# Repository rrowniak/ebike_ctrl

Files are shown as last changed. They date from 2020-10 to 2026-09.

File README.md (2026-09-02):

# ebike_ctrl
A small but powerful on-board computer displaying main parameters of almost any electric bike.
It concists of three parts:
* Motherboard - sits close to the BLDC driver and battery. Main responsibility is to gather all needed data like battery voltage, temperatures, current, hall sensor output and so on. The motherboard communicates with UI module via CAN bus.
* Current sensor. This is a hardware module (no firmware needed) connected to the motherboard.
* UI - displays all valuable info to a user. It reads what the motherboard is sending via CAN bus, then interprets the data, does additional calculations and displays on EA DOGXL240W-7 (240x128 pixel COG LCD).

## Features

* Displays current up to +/- 100A, voltage up to 100V and battery percentage

* Current speed, distance traveled (three profiles)

* Consumption in Wh, Wh/km +gain from regenerative charging

* Temperatures: ambient, motor, battery, driver

* Allows for changing views

* and more

## Requirements and dependencies

* GNU Arm Embedded Toolchain

* [l_rr library](https://github.com/rrowniak/l_rr)

## License

Copyright (c) 2020 Rafal Rowniak rrowniak.com

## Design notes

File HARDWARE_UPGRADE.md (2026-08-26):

# Hardware Upgrade Plan

The ebike controller consists of two independent STM32 units — **Motherboard** and **UI**.
This document tracks the planned hardware upgrade, split into two phases.

## Phase 1 — UI Unit

Replaces the current STM32F103C8 + HD44780 16×2 LCD with modern components.

### Selected parts

| Component | Part | Role |
|---|---|---|
| MCU | **NUCLEO-G431KB** (STM32G431CB in UFQFPN32 package, 128 KB flash / 32 KB RAM) | Main controller, FDCAN, better ADC |
| Display | **EA DOGXL240W-7** (240×128 COG LCD, SPI) | Primary display — sunlight-readable |
| Temperature sensor | **LM35** (analog output, −55…+150 °C) | Ambient/display temperature monitoring |
| EEPROM | **24L256** (256 Kbit I²C) | Vehicle configuration storage |
| CAN transceiver | **MCP2562** (high-speed CAN) | CAN bus interface to Motherboard |

### Rationale

- **STM32G431CB** — active product (≥2036), FDCAN (CAN 2.0 compatible), 12-bit ADC with
  hardware oversampling, 32 KB RAM handles the new display framebuffer, same CubeMX/HAL
  workflow. See `MCU.md` for full analysis.
- **EA DOGXL240W-7** — 240×128 COG LCD with SPI, sunlight-readable, bare-metal driver
  friendly. Replaces the Sharp Memory LCD option from earlier discussions.
- **LM35** — simple analog temperature sensor, direct ADC read, no digital protocol needed.
- **24L256** — same I²C EEPROM family already used in the current UI firmware
  (`lrr_eeprom_24LC256`), straightforward port.
- **MCP2562** — CAN 2.0 high-speed transceiver; pairs with the G431's FDCAN peripheral.

### Key files

- `UI/firmware/` — the old UI firmware project (CubeMX-generated, `firmware.ioc`)
- `UI/firmware2/` — the new/current UI firmware project (CubeMX-generated, `firmware2.ioc`)
- `include/bike_can_protocol.h` — shared CAN wire format (both sides)

### Migration notes

- FDCAN HAL API differs from bxCAN — `Src/can.c` and its test fake must be reworked.
- Display driver is new; existing `ui.c` abstraction layer keeps app logic untouched.
- `l_rr` library drivers need porting to G4 HAL; matching `stm32_drv_fake` fakes too.
- Deploy path (UART bootloader via `deploy.sh`) is preserved on the G431.

## Phase 2 — Motherboard + BMS

Upgrade the Motherboard unit (and potentially the BMS) to the same MCU family.
TBD — details to be added once Phase 1 is complete.

## Timeline

| Phase | Scope | Status |
|---|---|---|
| Phase 1 | UI unit only | In progress |
| Phase 2 | Motherboard + BMS | Planned |

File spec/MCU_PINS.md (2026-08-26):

# STM32G431KB Pin Reference & NUCLEO-G431KB Board Constraints

> Source: DS12589 Rev 6 (datasheet), RM0440 (reference manual), UM2397 Rev 2 (NUCLEO-G431KB user manual)
> Package: UFQFPN32 / LQFP32 — 32 pins total
>
> **⚠️ This document covers the full G4 family. For the UFQFPN32 package (STM32G431KB),
> only PA0–PA15, PB0, PB3–PB8, and PF0–PF1 are bonded out. Pins marked ✕ in the AF
> tables do NOT exist on the 32-pin package. See Section 7, Note 1 for details.**

---

## 1. STM32G431KB LQFP32 Pin Map

| Pin | Name | Type | Notes |
|-----|---|---|---|
| 1 | VDD | Power | 1.71–3.6V |
| 2 | PF0 / OSC_IN | I/O | HSE oscillator input |
| 3 | PF1 / OSC_OUT | I/O | HSE oscillator output |
| 4 | PG10 / NRST | I/O | Reset (active low) — **not available as GPIO** |
| 5 | PA0 | I/O | ADC1_IN1 |
| 6 | PA1 | I/O | ADC1_IN2 |
| 7 | PA2 | I/O | ADC1_IN3 |
| 8 | PA3 | I/O | ADC1_IN4 |
| 9 | PA4 | I/O | ADC1_IN5 |
| 10 | PA5 | I/O | ADC1_IN6 |
| 11 | PA6 | I/O | ADC1_IN7 |
| 12 | PA7 | I/O | ADC1_IN8 |
| 13 | PA8 | I/O | — |
| 14 | PA9 | I/O | — |
| 15 | PA10 | I/O | — |
| 16 | PA11 | I/O | ADC2_IN11 |
| 17 | PA12 | I/O | ADC2_IN12 |
| 18 | VSS | Power | Ground |
| 19 | PA13 | I/O | **SWDIO** (debug) |
| 20 | PA14 | I/O | **SWCLK** (debug) |
| 21 | VDDA | Power | Analog supply |
| 22 | VSS | Power | Ground |
| 23 | PB0 | I/O | ADC1_IN1 / ADC2_IN1 |
| 24 | VDD | Power | — |
| 25 | PB8 / BOOT0 | I/O | BOOT0 selection |
| 26 | PB7 | I/O | — |
| 27 | PB6 | I/O | — |
| 28 | PB5 | I/O | — |
| 29 | PB4 | I/O | — |
| 30 | PB3 | I/O | — |
| 31 | PA15 | I/O | — |
| 32 | VSS | Power | Ground |

---

## 2. Alternate Function Mapping (DS12589 Table 13)

### AF Number Assignment Summary

| AF | Peripheral Group |
|----|---|
| AF0 | SYS_AF: MCO, SWD (SWDIO/SWCLK), JTAG (JTDI/JTDO/NJTRST), TRACE, RTC_REFIN |
| AF1 | LPTIM1, TIM1/TIM2/TIM15/TIM16/TIM17 |
| AF2 | TIM1/TIM2/TIM3/TIM4/TIM8/TIM15, GPCOMP |
| AF3 | SAI1, USB, TIM8/TIM15, GPCOMP, I2C3 |
| AF4 | I2C1/I2C2/I2C3, TIM1/TIM8/TIM16/TIM17 |
| AF5 | SPI1/SPI2/SPI3, I2S2/I2S3, UART4 |
| AF6 | SPI2/SPI3, I2S2/I2S3, TIM1/TIM8 |
| AF7 | USART1/USART2/USART3 |
| AF8 | I2C3/I2C4, UART4, LPUART1, GPCOMP |
| AF9 | TIM1/TIM8/TIM15, FDCAN1 |
| AF10 | TIM2/TIM3/TIM4/TIM8/TIM17, LPTIM1, FDCAN1 |
| AF11 | LPUART1, SAI1, TIM1 |
| AF12 | SAI1, OPAMP2 |
| AF13 | UART4, SAI1, TIM2/TIM15, UCPD1 |
| AF14 | Reserved |
| AF15 | EVENTOUT |

---

### PORT A — Full AF Table

| Pin | AF0 | AF1 | AF2 | AF3 | AF4 | AF5 | AF6 | AF7 | AF8 | AF9 | AF10 | AF11 | AF12 | AF13 | AF15 |
|-----|-----|-----|-----|-----|-----|-----|-----|-----|-----|-----|---|---|---|---|---|
| PA0 | — | TIM2_CH1 | — | COMP1_OUT | — | — | — | USART2_CTS | — | — | COMP1_OUT | LPUART1_CTS | OPAMP1_OUT | — | EVENTOUT |
| PA1 | — | TIM2_CH2 | TIM15_CH1 | COMP1_OUT | — | — | — | USART2_RTS_DE | — | — | COMP1_OUT | LPUART1_RTS_DE | OPAMP2_OUT | SAI1_MCLK_A | EVENTOUT |
| PA2 | — | TIM2_CH3 | TIM15_CH2 | — | — | — | — | USART2_TX | LPUART1_TX | — | COMP2_OUT | — | — | SAI1_SCK_A | EVENTOUT |
| PA3 | — | TIM2_CH4 | — | COMP1_OUT | — | — | — | USART2_RX | LPUART1_RX | — | COMP2_OUT | — | — | SAI1_FS_A | EVENTOUT |
| PA4 | — | — | — | COMP1_OUT | — | SPI1_NSS | SPI3_NSS | USART2_CK | — | — | — | — | — | — | EVENTOUT |
| PA5 | — | TIM2_CH1 | TIM2_ETR | COMP1_OUT | — | SPI1_SCK | — | — | — | — | — | — | — | — | EVENTOUT |
| PA6 | — | TIM3_CH1 | TIM15_CH1 | — | TIM16_BKIN | SPI1_MISO | — | — | — | COMP2_OUT | — | — | — | SAI1_SCK_B | EVENTOUT |
| PA7 | — | TIM3_CH2 | TIM17_CH1 | COMP1_OUT | TIM17_CH2 | SPI1_MOSI | — | — | — | — | — | — | — | SAI1_FS_B | EVENTOUT |
| PA8 | MCO | TIM1_CH1 | — | — | — | — | SPI1_MOSI | USART1_CK | — | TIM8_BKIN2 | FDCAN1_TX | — | — | — | EVENTOUT |
| PA9 | — | TIM1_CH2 | — | — | — | — | SPI1_SCK | USART1_TX | I2C3_SCL | — | FDCAN1_RX | LPUART1_TX | — | — | EVENTOUT |
| PA10 | — | TIM1_CH3 | — | — | — | — | SPI1_MISO | USART1_RX | I2C3_SDA | — | — | LPUART1_RX | — | — | EVENTOUT |
| PA11 | — | TIM1_CH4 | — | COMP1_OUT | I2C1_SDA | — | — | USART1_CTS | — | FDCAN1_RX¹ | USB_DM | — | — | — | EVENTOUT |
| PA12 | — | — | — | COMP1_OUT | I2C1_SCL | — | — | USART1_RTS_DE | — | FDCAN1_TX¹ | USB_DP | — | — | — | EVENTOUT |
| PA13 | SWDIO | — | — | — | I2C1_SCL | — | — | — | — | — | — | — | — | — | EVENTOUT |
| PA14 | SWCLK | — | — | — | I2C1_SDA | — | — | — | — | TIM1_BKIN | USART2_TX | SAI1_FS_B | — | — | EVENTOUT |
| PA15 | JTDI | TIM2_CH1 | TIM8_CH1 | — | I2C1_SCL | SPI1_NSS | SPI3_NSS | USART2_RX | UART4_RTS_DE | TIM1_BKIN | TIM2_ETR | — | — | — | EVENTOUT |

> ¹ AF9 on PA11/PA12: The datasheet (DS12589 Table 13) lists TIM1_BKIN2 (PA11) and
> TIM1_ETR (PA12) on AF9. However, **CubeMX and ST community reports confirm FDCAN1_RX
> on PA11 and FDCAN1_TX on PA12 as AF9** for the G431KB. The entries above reflect the
> CubeMX-verified mapping. If using a different G4 variant, verify against your specific
> datasheet revision.

### PORT B — Full AF Table

> **Pins marked ✕ are NOT bonded out on UFQFPN32/LQFP32 (STM32G431KB).** They exist on
> LQFP48+ packages (G431CB, G431RB, etc.) but cannot be used on the 32-pin variant.

| Pin | AF0 | AF1 | AF2 | AF3 | AF4 | AF5 | AF6 | AF7 | AF8 | AF9 | AF10 | AF11 | AF12 | AF13 | AF15 |
|-----|-----|-----|-----|-----|-----|-----|-----|-----|-----|-----|---|---|---|---|---|
| PB0 | — | — | TIM3_CH3 | TIM1_ETR | TIM16_CH1 | — | SPI1_MOSI | — | — | TIM3_ETR | — | — | — | OPAMP1_OUT | EVENTOUT |
| PB1 ✕ | — | — | TIM3_CH4 | — | TIM16_CH1N | — | — | USART3_RTS_DE | — | — | — | LPUART1_RTS_DE | OPAMP1_OUT | OPAMP3_OUT | EVENTOUT |
| PB2 ✕ | — | — | — | — | — | — | — | — | — | — | — | — | — | — | EVENTOUT |
| PB3 | JTDO | — | — | — | — | SPI1_SCK | SPI3_SCK | — | — | — | — | — | — | — | EVENTOUT |
| PB4 | NJTRST | — | TIM3_CH1 | — | — | SPI1_MISO | SPI3_MISO | — | — | — | — | — | — | — | EVENTOUT |
| PB5 | — | LPTIM1_IN1 | TIM3_CH2 | — | I2C1_SMBA | SPI1_MOSI | — | — | — | — | — | — | — | — | EVENTOUT |
| PB6 | — | LPTIM1_ETR | TIM4_CH1 | SAI1_FS_B | I2C1_SCL | — | — | USART1_TX | — | — | — | — | — | — | EVENTOUT |
| PB7 | — | LPTIM1_IN2 | TIM4_CH2 | — | I2C1_SDA | — | — | USART1_RX | — | — | — | — | — | — | EVENTOUT |
| PB8 | — | — | TIM4_CH3 | SAI1_SCK_A | — | SPI1_SCK | — | — | I2C1_SCL | TIM16_CH1 | — | — | — | SAI1_FS_B | EVENTOUT |
| PB9 ✕ | — | TIM17_CH1 | TIM4_CH4 | SAI1_D2 | I2C1_SDA | IR_OUT | — | USART3_TX | COMP2_OUT | FDCAN1_TX | TIM8_CH3 | TIM1_CH3N | SAI1_FS_A | — | EVENTOUT |
| PB10 ✕ | — | — | TIM2_CH3 | SAI1_SCK_B | I2C2_SCL | SPI2_SCK | — | USART3_TX | — | FDCAN1_TX | — | — | — | — | EVENTOUT |
| PB11 ✕ | — | — | TIM2_CH4 | SAI1_D2 | I2C2_SDA | — | — | USART3_RX | — | FDCAN1_RX | — | — | — | — | EVENTOUT |
| PB12 ✕ | — | LPTIM1_OUT | — | COMP2_OUT | I2C2_SMBA | SPI2_NSS | — | USART3_CK | — | FDCAN1_RX | — | — | — | — | EVENTOUT |
| PB13 ✕ | — | — | — | COMP4_OUT | I2C2_SCL | SPI2_SCK | TIM1_CH1N | USART3_CTS | LPUART1_CTS | — | — | — | — | — | EVENTOUT |
| PB14 ✕ | — | TIM15_CH1 | — | — | I2C2_SDA | SPI2_MISO | TIM1_CH2N | USART3_RTS_DE | COMP4_OUT | — | — | — | — | — | EVENTOUT |
| PB15 ✕ | RTC_REFIN | TIM15_CH2 | TIM15_CH1N | COMP3_OUT | TIM1_CH3N | SPI2_MOSI | — | — | — | — | — | — | — | — | EVENTOUT |

### PORT C — Full AF Table

> **All PORT C pins are ✕ NOT available on UFQFPN32/LQFP32 (STM32G431KB).**
> Included for reference when using LQFP48+ packages.

| Pin | AF0 | AF1 | AF2 | AF3 | AF4 | AF5 | AF6 | AF7 | AF8 | AF15 |
|-----|-----|-----|-----|-----|-----|-----|-----|-----|-----|---|
| PC0 ✕ | — | — | — | — | — | — | — | — | LPTIM1_IN1 | EVENTOUT |
| PC1 ✕ | — | — | — | — | — | — | — | — | LPTIM1_OUT | EVENTOUT |
| PC2 ✕ | — | — | — | — | — | — | — | — | LPTIM1_IN3 | EVENTOUT |
| PC3 ✕ | — | — | — | — | — | — | — | — | LPTIM1_ETR | EVENTOUT |
| PC4 ✕ | — | — | — | COMP1_OUT | — | — | — | — | LPTIM1_IN2 | EVENTOUT |
| PC5 ✕ | — | — | — | COMP1_OUT | — | — | — | — | LPTIM1_IN1 | EVENTOUT |
| PC6 ✕ | — | TIM3_CH1 | TIM8_CH1 | — | — | — | I2S2_MCK | — | — | EVENTOUT |
| PC7 ✕ | — | TIM3_CH2 | TIM8_CH2 | — | — | — | — | — | — | EVENTOUT |
| PC8 ✕ | — | TIM3_CH3 | TIM8_CH3 | — | — | — | — | — | — | EVENTOUT |
| PC9 ✕ | — | TIM3_CH4 | TIM8_CH4 | — | — | — | — | — | — | EVENTOUT |
| PC10 ✕ | — | — | TIM8_CH1N | — | — | UART4_TX | SPI3_SCK | USART3_TX | — | EVENTOUT |
| PC11 ✕ | — | — | TIM8_CH2N | — | — | UART4_RX | SPI3_MISO | USART3_RX | I2C3_SDA | EVENTOUT |
| PC12 ✕ | — | — | TIM8_CH3N | — | TIM8_CH4 | — | SPI3_MOSI | USART3_CK | UCPD1_FRSTX | EVENTOUT |
| PC13 ✕ | — | — | TIM1_BKIN | — | TIM1_CH1N | — | TIM8_CH4N | — | — | EVENTOUT |
| PC14 ✕ | — | — | — | — | — | — | — | — | — | EVENTOUT |
| PC15 ✕ | — | — | — | — | — | — | — | — | — | EVENTOUT |

### PORT F — Full AF Table

> **PF2, PF9, PF10 are ✕ NOT available on UFQFPN32/LQFP32.**
> PF0/PF1 are available but primarily for HSE oscillator (requires SB8/SB11 on NUCLEO).

| Pin | AF0 | AF1 | AF2 | AF3 | AF4 | AF5 | AF6 | AF7 | AF8 | AF15 |
|-----|-----|-----|-----|-----|-----|-----|-----|-----|-----|---|
| PF0 | — | — | — | — | I2C2_SDA | SPI2_NSS | TIM1_CH3N | — | — | EVENTOUT |
| PF1 | — | — | — | — | — | SPI2_SCK | — | — | — | EVENTOUT |
| PF2 ✕ | — | — | — | — | I2C2_SMBA | — | — | — | — | EVENTOUT |
| PF9 ✕ | — | — | TIM15_CH1 | — | — | SPI2_SCK | — | — | — | EVENTOUT |
| PF10 ✕ | — | — | TIM15_CH2 | — | — | SPI2_SCK | — | — | — | EVENTOUT |

### PORT G

| Pin | AF0 | AF15 | Notes |
|-----|-----|---|---|
| PG10 | MCO | EVENTOUT | **NRST pin — not available as GPIO** on any package |

---

## 3. Peripheral-to-Pin Conflict Matrix

When a peripheral is mapped to a pin, **all other AFs on that pin become unavailable**. Below are the key conflicts for each peripheral.

> **Pins marked ✕ are NOT available on UFQFPN32.** Conflict info is included for LQFP48+ reference.

### I2C1

| Signal | Available Pins (UFQFPN32) | AF | Conflicts |
|---|---|-----|---|
| I2C1_SCL | PA13, PA15, PB6, PB8 | AF4 | PA13=SWDIO, PA15=SPI1_NSS/USART2_RX/JTDI, PB6=USART1_TX, PB8=SPI1_SCK |
| I2C1_SDA | PA11, PA14, PB7, PB5 | AF4 | PA11=USB_DM/FDCAN1_RX, PA14=SWCLK/USART2_TX, PB7=USART1_RX, PB5=SPI1_MOSI |
| I2C1_SMBA | PB5 | AF4 | PB5=SPI1_MOSI/TIM3_CH2 |

**I2C1 conflicts (UFQFPN32):**
- PA13+PA14: SWD pins — **cannot use for I2C1** without losing debug
- PA15+PB7: Common NUCLEO I2C pair (SB2/SB3) — conflicts with USART2_RX and USART1_RX
- PB6+PB7: TIM4_CH1/TIM4_CH2 and USART1_TX/USART1_RX — using I2C1 here blocks USART1

### I2C2

| Signal | Available Pins (UFQFPN32) | AF | Conflicts |
|---|---|-----|---|
| I2C2_SCL | PF0 (oscillator only) | AF4 | PF0=OSC_IN — only available without external crystal |
| I2C2_SDA | PF0 (oscillator only) | AF4 | PF0=OSC_IN — only available without external crystal |
| I2C2_SMBA | PF2 ✕ | AF4 | Not available on UFQFPN32 |

**I2C2 conflicts:**
- **No practical I2C2 option on UFQFPN32** — PB10/PB11/PB12/PB13 are not bonded out
- PF0 can serve as I2C2_SDA but conflicts with HSE oscillator
- PF0: Only available when not using external crystal

### I2C3

| Signal | Available Pins (UFQFPN32) | AF | Conflicts |
|---|---|-----|---|
| I2C3_SCL | PA9, PA13, PA15, PB8 | AF4 | PA9=USART1_TX/SPI1_SCK, PA13=SWDIO, PA15=JTDI/USART2_RX, PB8=SPI1_SCK |
| I2C3_SDA | PA10, PA14 | AF4 | PA10=USART1_RX, PA14=SWCLK/USART2_TX |

### USART1

| Signal | Available Pins (UFQFPN32) | AF | Conflicts |
|---|---|-----|---|
| USART1_TX | PA9, PB6 | AF7 | PA9=SPI1_SCK/I2C3_SCL, PB6=TIM4_CH1/I2C1_SCL |
| USART1_RX | PA10, PB7 | AF7 | PA10=SPI1_MISO/I2C3_SDA, PB7=TIM4_CH2/I2C1_SDA |
| USART1_CTS | PA11 | AF7 | PA11=FDCAN1_RX/USB_DM |
| USART1_RTS_DE | PA12 | AF7 | PA12=FDCAN1_TX/USB_DP |
| USART1_CK | PA8 | AF7 | PA8=MCO/TIM1_CH1 |

### USART2

| Signal | Available Pins (UFQFPN32) | AF | Conflicts |
|---|---|-----|---|
| USART2_TX | PA2, PA14 | AF7 | PA2=LPUART1_TX/COMP2_OUT (default VCP on NUCLEO), PA14=SWCLK |
| USART2_RX | PA3, PA15 | AF7 | PA3=LPUART1_RX/COMP2_OUT (default VCP on NUCLEO), PA15=JTDI/SPI1_NSS |
| USART2_CTS | PA0 | AF7 | PA0=TIM2_CH1/COMP1_OUT |
| USART2_RTS_DE | PA1 | AF7 | PA1=TIM2_CH2/LPUART1_RTS_DE |
| USART2_CK | PA4 | AF7 | PA4=SPI1_NSS/SPI3_NSS |

### USART3

| Signal | Available Pins (UFQFPN32) | AF | Conflicts |
|---|---|-----|---|
| USART3_TX | **None** ✕ | AF7 | PB9/PB10/PC10 not available on UFQFPN32 |
| USART3_RX | **None** ✕ | AF7 | PB11/PC11 not available on UFQFPN32 |
| USART3_CK | **None** ✕ | AF7 | PB12/PC12 not available on UFQFPN32 |
| USART3_CTS | **None** ✕ | AF7 | PB13 not available on UFQFPN32 |
| USART3_RTS_DE | **None** ✕ | AF7 | PB1/PB14 not available on UFQFPN32 |

> **USART3 is not usable on UFQFPN32** — all USART3 pins require PB9–PB15 or PC pins.

### LPUART1

| Signal | Available Pins (UFQFPN32) | AF | Conflicts |
|---|---|-----|---|
| LPUART1_TX | PA2, PA9 | AF8 | PA2=USART2_TX (default VCP), PA9=USART1_TX/SPI1_SCK |
| LPUART1_RX | PA3, PA10 | AF8 | PA3=USART2_RX (default VCP), PA10=USART1_RX/SPI1_MISO |
| LPUART1_CTS | PA0 | AF8 | PA0=TIM2_CH1 |
| LPUART1_RTS_DE | PA1 | AF8 | PA1=TIM2_CH2 |

### UART4

| Signal | Available Pins (UFQFPN32) | AF | Conflicts |
|---|---|-----|---|
| UART4_TX | **None** ✕ | AF5 | PC10 not available on UFQFPN32 |
| UART4_RX | **None** ✕ | AF5 | PC11 not available on UFQFPN32 |
| UART4_RTS_DE | PA15 | AF8 | PA15=JTDI/SPI1_NSS/USART2_RX |

> **UART4 TX/RX not usable on UFQFPN32** — requires PC10/PC11.

### SPI1

| Signal | Available Pins (UFQFPN32) | AF | Conflicts |
|---|---|-----|---|
| SPI1_SCK | PA5, PA9, PB3 | AF5 | PA5=TIM2_CH1 (SB2 constraint), PA9=USART1_TX/I2C3_SCL, PB3=JTDO/SPI3_SCK |
| SPI1_MISO | PA6, PA10, PB4 | AF5 | PA6=TIM3_CH1 (SB3 constraint), PA10=USART1_RX/I2C3_SDA, PB4=NJTRST/SPI3_MISO |
| SPI1_MOSI | PA7, PA8, PB5 | AF5 | PA7=TIM3_CH2, PA8=USART1_CK/TIM1_CH1, PB5=TIM3_CH2 |
| SPI1_NSS | PA4, PA15 | AF5 | PA4=SPI3_NSS/USART2_CK, PA15=JTDI/USART2_RX |

### SPI2

| Signal | Available Pins (UFQFPN32) | AF | Conflicts |
|---|---|-----|---|
| SPI2_SCK | PF0, PF1 (oscillator only) | AF5 | PF0=OSC_IN, PF1=OSC_OUT — only available without external crystal |
| SPI2_MISO | **None** ✕ | AF5 | PB14 not available on UFQFPN32 |
| SPI2_MOSI | **None** ✕ | AF5 | PB15/PB1 not available on UFQFPN32 |
| SPI2_NSS | PF0 (oscillator only) | AF5 | PF0=OSC_IN |

> **SPI2 is not practical on UFQFPN32** — MISO/MOSI require PB14/PB15/PB1.

### SPI3

| Signal | Available Pins (UFQFPN32) | AF | Conflicts |
|---|---|-----|---|
| SPI3_SCK | PB3 | AF6 | PB3=JTDO/SPI1_SCK |
| SPI3_MISO | PB4 | AF6 | PB4=NJTRST/SPI1_MISO |
| SPI3_MOSI | **None** ✕ | AF6 | PC12 not available on UFQFPN32 |
| SPI3_NSS | PA4, PA15 | AF6 | PA4=SPI1_NSS/USART2_CK, PA15=JTDI/USART2_RX |

> **SPI3 MOSI not available on UFQFPN32** — requires PC12.

### FDCAN1

> **⚠️ AF table discrepancy:** The PORT A AF table (Section 2) lists FDCAN1_TX on PA8 (AF10)
> and FDCAN1_RX on PA9 (AF10). However, **CubeMX for the G431KB only offers FDCAN1 on
> PA11 (RX) / PA12 (TX) as AF9**. The PA8/PA9 entries appear to be for a different package
> variant or a datasheet error. PA11/PA12 FDCAN1 is confirmed working by ST Community reports.
> The AF table for PA11/PA12 below reflects the CubeMX-verified mapping.

| Signal | Available Pins (UFQFPN32) | AF | Conflicts |
|---|---|-----|---|
| FDCAN1_TX | PA12 | AF9 | PA12=USB_DP/USART1_RTS_DE/TIM1_ETR/I2C1_SCL/COMP1_OUT |
| FDCAN1_RX | PA11 | AF9 | PA11=USB_DM/USART1_CTS/TIM1_CH4/I2C1_SDA/COMP1_OUT |

**Remap alternatives (not verified on UFQFPN32 — listed for reference only):**
- PA8 (AF10) = FDCAN1_TX — conflicts with MCO/TIM1_CH1/USART1_CK
- PA9 (AF10) = FDCAN1_RX — conflicts with USART1_TX/SPI1_SCK/I2C3_SCL
- PB8 (AF10) = FDCAN1_TX — remap option (PB9/PB10 not available on UFQFPN32)

### TIM1

| Signal | Available Pins (UFQFPN32) | AF | Conflicts |
|---|---|-----|---|
| TIM1_CH1 | PA8 | AF1 | PA8=MCO/USART1_CK |
| TIM1_CH2 | PA9 | AF1 | PA9=USART1_TX/SPI1_SCK |
| TIM1_CH3 | PA10 | AF1 | PA10=USART1_RX/SPI1_MISO |
| TIM1_CH4 | PA11 | AF1 | PA11=FDCAN1_RX/USB_DM |
| TIM1_CH1N | PB13 ✕ | AF6 | Not available on UFQFPN32 |
| TIM1_CH2N | PB14 ✕ | AF6 | Not available on UFQFPN32 |
| TIM1_CH3N | PB15 ✕ | AF4 | Not available on UFQFPN32 |
| TIM1_ETR | PA12 | AF9 | PA12=FDCAN1_TX/USB_DP |
| TIM1_BKIN | PA15 | AF9 | PA15=JTDI/USART2_RX |
| TIM1_BKIN2 | PA8 | AF9 | PA8=MCO/USART1_CK |

### TIM2

| Signal | Available Pins (UFQFPN32) | AF | Conflicts |
|---|---|-----|---|
| TIM2_CH1 | PA0, PA5, PA15 | AF1 | PA0=COMP1_OUT/USART2_CTS, PA5=SPI1_SCK (SB2 constraint), PA15=JTDI/USART2_RX |
| TIM2_CH2 | PA1, PB3 | AF1 | PA1=COMP1_OUT/LPUART1_RTS_DE, PB3=JTDO/SPI1_SCK |
| TIM2_CH3 | PA2 | AF1 | PA2=USART2_TX/LPUART1_TX |
| TIM2_CH4 | PA3 | AF1 | PA3=USART2_RX/LPUART1_RX |
| TIM2_ETR | PA5, PA15 | AF2 | PA5=SPI1_SCK, PA15=JTDI/USART2_RX |

### TIM3

| Signal | Available Pins (UFQFPN32) | AF | Conflicts |
|---|---|-----|---|
| TIM3_CH1 | PA6, PB4 | AF2 | PA6=SPI1_MISO (SB3 constraint), PB4=NJTRST/SPI1_MISO |
| TIM3_CH2 | PA7, PB5 | AF2 | PA7=SPI1_MOSI, PB5=SPI1_MOSI |
| TIM3_CH3 | PB0 | AF2 | PB0=SPI1_MOSI |
| TIM3_CH4 | PB1 ✕ | AF2 | Not available on UFQFPN32 |
| TIM3_ETR | PB0 | AF9 | PB0=SPI1_MOSI |

### TIM4

| Signal | Available Pins (UFQFPN32) | AF | Conflicts |
|---|---|-----|---|
| TIM4_CH1 | PB6 | AF2 | PB6=I2C1_SCL/USART1_TX |
| TIM4_CH2 | PB7 | AF2 | PB7=I2C1_SDA/USART1_RX |
| TIM4_CH3 | PB8 | AF2 | PB8=SPI1_SCK/I2C1_SCL |
| TIM4_CH4 | PB9 ✕ | AF2 | Not available on UFQFPN32 |

### TIM8

> **TIM8 is not usable on UFQFPN32** — all TIM8 pins require PC6–PC13.

| Signal | Available Pins (UFQFPN32) | AF | Conflicts |
|---|---|-----|---|
| TIM8_CH1 | **None** ✕ | AF2 | PC6 not available on UFQFPN32 |
| TIM8_CH2 | **None** ✕ | AF2 | PC7 not available on UFQFPN32 |
| TIM8_CH3 | **None** ✕ | AF2 | PC8 not available on UFQFPN32 |
| TIM8_CH4 | **None** ✕ | AF2 | PC9/PC12 not available on UFQFPN32 |
| TIM8_CH1N | **None** ✕ | AF2 | PC10 not available on UFQFPN32 |
| TIM8_CH2N | **None** ✕ | AF2 | PC11 not available on UFQFPN32 |
| TIM8_CH3N | **None** ✕ | AF2 | PC12 not available on UFQFPN32 |
| TIM8_CH4N | **None** ✕ | AF6 | PC13 not available on UFQFPN32 |
| TIM8_BKIN2 | PA8 | AF9 | PA8=MCO/TIM1_CH1 |

### TIM15

| Signal | Available Pins (UFQFPN32) | AF | Conflicts |
|---|---|-----|---|
| TIM15_CH1 | PA1, PA6 | AF2 | PA1=TIM2_CH2, PA6=TIM3_CH1 |
| TIM15_CH2 | PA2 | AF2 | PA2=USART2_TX |

### TIM16

| Signal | Available Pins (UFQFPN32) | AF | Conflicts |
|---|---|-----|---|
| TIM16_CH1 | PA6, PB8 | AF4 | PA6=TIM3_CH1/SPI1_MISO, PB8=SPI1_SCK/I2C1_SCL |
| TIM16_CH1N | PB1 ✕ | AF4 | Not available on UFQFPN32 |

### TIM17

| Signal | Available Pins (UFQFPN32) | AF | Conflicts |
|---|---|-----|---|
| TIM17_CH1 | PA7 | AF2 | PA7=SPI1_MOSI/TIM3_CH2 |

### USB

| Signal | Available Pins | AF | Conflicts |
|---|---|-----|---|
| USB_DM | PA11 | AF10 | PA11=TIM1_CH4/USART1_CTS/I2C1_SDA |
| USB_DP | PA12 | AF10 | PA12=TIM1_ETR/USART1_RTS_DE/I2C1_SCL |

### DAC

| Signal | Available Pins | Notes |
|---|---|---|
| DAC1_OUT1 | PA4 | Also SPI1_NSS/USART2_CK — use as analog only |
| DAC1_OUT2 | PA5 | Also SPI1_SCK — use as analog only |
| DAC1_OUT3 | PA6 | Also TIM3_CH1/SPI1_MISO — use as analog only |

---

## 4. NUCLEO-G431KB (MB1430) Board Constraints

### 4.1 Permanently Reserved Pins

| Pin | Reserved By | Reason |
|-----|---|---|
| PA13 | ST-LINK SWDIO | SWD debug data line |
| PA14 | ST-LINK SWCLK | SWD debug clock |
| PG10/NRST | ST-LINK NRST | Reset line (pin 4) |

**These 3 pins MUST NOT be reconfigured** if you need debugging/programming.

### 4.2 Solder Bridge Configuration

| SB# | Signal | Default | Effect when ON | Effect when OFF |
|-----|---|---|---|---|
| SB1 | T_VCP_TX | **ON** | PA2 connected to ST-LINK Virtual COM Port TX | PA2 free (VCP disabled) |
| SB12 | T_VCP_RX | **ON** | PA3 connected to ST-LINK Virtual COM Port RX | PA3 free (VCP disabled) |
| SB2 | ARD_A4 | **ON** | PB7 routed to Arduino A4 (I2C SDA position); **PA5 must be floating input** | PB7 available as D4; PA5 can be used normally |
| SB3 | ARD_A5 | **ON** | PA15 routed to Arduino A5 (I2C SCL position); **PA6 must be floating input** | PA15 available as D5; PA6 can be used normally |
| SB4 | T_SWO | **ON** | PB3 connected to ST-LINK SWO trace | PB3 free (trace disabled) |
| SB8 | PF0 to D7 | **OFF** | PF0-OSC_IN connected to Arduino D7 (CN4 pin 10) | PF0 not routed to header |
| SB11 | PF1 to D8 | **OFF** | PF1-OSC_OUT connected to Arduino D8 (CN4 pin 11) | PF1 not routed to header |
| SB9+SB10 | HSE XTAL | **OFF** | External 24 MHz crystal connected to HSE | No external crystal |
| SB13 | HSE from MCO | **OFF** | ST-LINK MCO (25 MHz) feeds HSE via PF0 | No MCO clock to HSE |
| SB14 | ARD_A2 | **OFF** | PA3 connected to Arduino A2 analog header | PA3 not routed to A2 |

### 4.3 SB2/SB3 Side Effects (Critical!)

When **SB2 is ON** (default):
- PB7 = I2C1_SDA on Arduino A4 position
- **PA5 must be left as floating input** — do NOT configure it as output, alternate function, or analog

When **SB3 is ON** (default):
- PA15 = I2C1_SCL on Arduino A5 position
- **PA6 must be left as floating input** — do NOT configure it as output, alternate function, or analog

### 4.4 Arduino Nano V3 Connector Mapping

#### CN3 (Left Connector)

| CN3 Pin | Arduino Name | STM32 Pin | AF7 Function | Notes |
|---|---|---|---|---|
| 1 | TX | PA10 | USART1_RX | Label is misleading — PA10 is USART1 RX |
| 2 | RX | PA9 | USART1_TX | Label is misleading — PA9 is USART1 TX |
| 3 | RST | PG10/NRST | Reset | Connected to NRST |
| 4 | GND | — | Ground | |
| 5 | D2 | PB3 | SPI1_SCK | SB4 default ON (SWO trace) |
| 6 | D3 | PB4 | SPI1_MISO / TIM3_CH1 | |
| 7 | A5 | PA15 | I2C1_SCL | SB3 default ON — I2C on A5 |
| 8 | A4 | PB7 | I2C1_SDA | SB2 default ON — I2C on A4 |
| 9 | A3 | PA4 | ADC1_IN5 | |
| 10 | A2 | PA3 | ADC1_IN4 / USART2_RX | SB14 default OFF |
| 11 | A1 | PA1 | ADC1_IN2 / TIM2_CH2 | |
| 12 | A0 | PA0 | ADC1_IN1 / TIM2_CH1 | |
| 13 | VREF+ | VREF+ | ADC reference | |
| 14 | 3V3 | — | 3.3V output | |
| 15 | GND | — | Ground | |

#### CN4 (Right Connector)

| CN4 Pin | Arduino Name | STM32 Pin | AF Function | Notes |
|---|---|---|---|---|
| 1 | D13 | PB5 | SPI1_MOSI | User LED (LD2) connected here |
| 2 | D12 | PB4 | SPI1_MISO / TIM3_CH1 | Shared with CN3 D3 |
| 3 | D11 | PB5 | SPI1_MOSI | Duplicate of D13 |
| 4 | D10 | PA11 | USB_DM / TIM1_CH4 | |
| 5 | D9 | PA8 | TIM1_CH1 / FDCAN1_TX | |
| 6 | D8 | PF1 | OSC_OUT | SB11 default OFF |
| 7 | D7 | PF0 | OSC_IN | SB8 default OFF |
| 8 | D6 | PB6 | I2C1_SCL / USART1_TX | |
| 9 | D5 | PA15 | I2C1_SCL / SPI1_NSS | SB3 default ON — conflicts with A5 |
| 10 | D4 | PB7 | I2C1_SDA / TIM4_CH2 | SB2 default ON — conflicts with A4 |
| 11 | D3 | PB3 | SPI1_SCK | SB4 default ON (SWO) |
| 12 | D2 | PB2 ✕ | GPIO only | **Not available on UFQFPN32** — no bonded pin |
| 13 | GND | — | Ground | |
| 14 | 5V | — | 5V output/input | |
| 15 | VIN | — | External power | |

---

## 5. Recommended Pin Assignments by Function (UFQFPN32 filtered)

> **Pins marked ✕ are NOT available on UFQFPN32.** Options using these pins are for
> LQFP48+ packages only.

### I2C Bus

| Option | SCL | SDA | Notes |
|---|-----|-----|---|
| **I2C1 on A4/A5** (default) | PA15 (AF4) | PB7 (AF4) | SB2+SB3 ON. PA5/PA6 must float |
| I2C1 on PB6/PB7 | PB6 (AF4) | PB7 (AF4) | Blocks USART1_TX/RX |
| I2C2 on PB10/PB11 ✕ | PB10 (AF4) | PB11 (AF4) | LQFP48+ only. Blocks USART3_TX/RX, SPI2 |
| I2C2 on PB13/PB11 ✕ | PB13 (AF4) | PB11 (AF4) | LQFP48+ only. Blocks USART3_CTS, SPI2 |
| I2C3 on PA9/PA10 | PA9 (AF4) | PA10 (AF4) | Blocks USART1_TX/RX |

### SPI Bus

| Option | SCK | MISO | MOSI | NSS | Notes |
|---|-----|---|---|-----|---|
| **SPI1 (default)** | PB3 (AF5) | PB4 (AF5) | PB5 (AF5) | PA4 or PA15 (AF5) | PB3=SWO (SB4 ON); PB5 has LED |
| SPI1 alt | PA5 (AF5) | PA6 (AF5) | PA7 (AF5) | PA4 (AF5) | Conflicts with SB2/SB3 side effects |
| SPI2 ✕ | PB10 (AF5) | PB14 (AF5) | PB15 (AF5) | PB12 (AF5) | LQFP48+ only. Blocks USART3 |
| SPI3 ✕ | PB3 (AF6) | PB4 (AF6) | PC12 (AF6) | PA15 (AF6) | LQFP48+ only (PC12 not on 32-pin) |

### USART Bus

| Option | TX | RX | CTS/RTS | Notes |
|---|----|----|---|---|
| **USART1** | PA9 (AF7) | PA10 (AF7) | PA11/PA12 (AF7) | Available on CN3 TX/RX pins |
| **USART2 (VCP)** | PA2 (AF7) | PA3 (AF7) | PA0/PA1 (AF7) | Default VCP. Cut SB1/SB12 to free PA2/PA3 |
| USART3 ✕ | PB10 (AF7) | PB11 (AF7) | PB13/PB1 (AF7) | LQFP48+ only. Blocks I2C2 and SPI2 |

### CAN Bus (FDCAN1)

| Option | TX | RX | Notes |
|---|----|----|---|
| **FDCAN1 (CubeMX default)** | PA12 (AF9) | PA11 (AF9) | Verified on G431KB. PA11/PA12 shared with USB |
| FDCAN1 (datasheet remap) ✕ | PA8 (AF10) | PA9 (AF10) | Not verified on G431KB. PA9 conflicts with USART1_TX |
| FDCAN1 ✕ | PB9 (AF9) | PB11 (AF9) | LQFP48+ only. PB9 conflicts with I2C1_SDA |
| FDCAN1 ✕ | PB10 (AF9) | PB12 (AF9) | LQFP48+ only. PB10 conflicts with I2C2_SCL |
| FDCAN1 ✕ | PB8 (AF10) | PB9 (AF10) | LQFP48+ only. Remap option |

### Timer PWM (UFQFPN32 filtered)

> Pins marked ✕ are not available on UFQFPN32.

| Timer | CH1 | CH2 | CH3 | CH4 | Notes |
|---|-----|-----|-----|-----|---|
| TIM1 | PA8 | PA9 | PA10 | PA11 | Advanced timer, complementary outputs on PB13/14/15 ✕ |
| TIM2 | PA0/PA5/PA15 | PA1/PB3 | PA2/PB10 ✕ | PA3/PB11 ✕ | 32-bit timer |
| TIM3 | PA6/PB4/PC6 ✕ | PA7/PB5/PC7 ✕ | PB0/PC8 ✕ | PB1 ✕/PC9 ✕ | |
| TIM4 | PB6 | PB7 | PB8 | PB9 ✕ | General purpose |

---

## 6. Quick Conflict Reference (UFQFPN32)

### Pins you CAN use freely (no board conflicts)

| Pin | Best Functions |
|-----|---|
| PA0 | ADC, TIM2_CH1, USART2_CTS |
| PA1 | ADC, TIM2_CH2, LPUART1_RTS_DE |
| PA4 | ADC, SPI1_NSS, DAC1_OUT1 |
| PA7 | SPI1_MOSI, TIM3_CH2 |
| PA8 | TIM1_CH1, D9 |
| PA11 | FDCAN1_RX, D10 |
| PA12 | FDCAN1_TX |
| PB0 | ADC, TIM3_CH3 |
| PB4 | SPI1_MISO, TIM3_CH1, D3/D12 |
| PB6 | USART1_TX, TIM4_CH1, D6 |
| PB8 | TIM4_CH3, I2C1_SCL (if SB8 not needed), FDCAN1_TX remap |

### Pins with board-level restrictions

| Pin | Restriction |
|-----|---|
| PA2 | SB1 default ON (VCP TX). Cut SB1 to use freely |
| PA3 | SB12 default ON (VCP RX). Cut SB12 to use freely |
| PA5 | **Must float** when SB2=ON (I2C on A4) |
| PA6 | **Must float** when SB3=ON (I2C on A5) |
| PA13 | **SWDIO** — never reconfigure |
| PA14 | **SWCLK** — never reconfigure |
| PA15 | SB3 default ON (I2C SCL on A5). Cut SB3 to use as D5 |
| PB3 | SB4 default ON (SWO trace). Cut SB4 to use freely |
| PB5 | User LED (LD2) active low — available but has LED |
| PB7 | SB2 default ON (I2C SDA on A4). Cut SB2 to use as D4 |
| PF0 | SB8 default OFF. Only on D7 if SB8 soldered. OSC_IN |
| PF1 | SB11 default OFF. Only on D8 if SB11 soldered. OSC_OUT |

### Pins NOT available on UFQFPN32

| Pin | Reason |
|-----|---|
| PB1 | Not bonded out on 32-pin package |
| PB2 | Not bonded out on 32-pin package |
| PB9–PB15 | Not bonded out on 32-pin package |
| PC0–PC15 | Not bonded out on 32-pin package |
| PF2, PF9, PF10 | Not bonded out on 32-pin package |
| PG10 | NRST — reset pin, not GPIO |
| VDD/VSS/VDDA | Power pins |

---

## 7. Important Notes

1. **⚠️ UFQFPN32 package constraint (STM32G431KB).** Only PB0, PB3–PB8 are bonded out on the 32-pin package. **PB1, PB2, PB9–PB15, PC0–PC15, and PF2/PF9/PF10 do NOT exist.** The AF tables and conflict matrices include these pins for completeness (useful when designing for LQFP48+ packages), but they are NOT usable on the G431KB. Always check the ✕ markers.

2. **Every pin can only serve ONE alternate function at a time.** Selecting AF4 for I2C1 on a pin precludes all other AFs on that same pin.

3. **I2C requires open-drain mode** with pull-ups. All other digital AFs typically use push-pull mode.

4. **⚠️ FDCAN1 AF discrepancy.** The datasheet (DS12589 Table 13) AF table lists FDCAN1_TX on PA8 (AF10) and FDCAN1_RX on PA9 (AF10). However, **CubeMX for the G431KB only offers FDCAN1 on PA11 (RX) / PA12 (TX) as AF9**. This is confirmed by ST Community reports. If your design requires FDCAN1, use PA11/PA12 — do not rely on the PA8/PA9 entries in the AF table.

5. **PF0/PF1 are oscillator pins.** If you need an external crystal, you cannot use these as GPIO. On the NUCLEO board, they are only routed to Arduino pins D7/D8 when SB8/SB11 are soldered.

6. **PA5 and PA6 have hidden restrictions** on the NUCLEO board due to the I2C solder bridges (SB2/SB3). Always check SB state before using these pins.

7. **USART1 TX/RX labels are swapped** on the NUCLEO CN3 connector (CN3 pin 1 = TX label = PA10 = USART1_RX, CN3 pin 2 = RX label = PA9 = USART1_TX).

8. **CN3/CN4 connector labels** on the NUCLEO-G431KB are swapped compared to other Nucleo-32 boards — this is a known design quirk.

9. **PA11/PA12 dual use.** These pins serve as both FDCAN1 (AF9) and USB (AF10). You cannot use FDCAN1 and USB simultaneously. CubeMX defaults to FDCAN1 when the FDCAN peripheral is enabled.

10. **FDCAN1 clock source.** The NUCLEO board has no dedicated CAN crystal. For accurate bit timing, solder SB13 to route ST-LINK MCO (25 MHz) to HSE, or use HSI16 with auto-calibration.

11. **DAC outputs** (PA4/PA5/PA6) are analog-only — they cannot be used as digital GPIO when the DAC is enabled on those channels.

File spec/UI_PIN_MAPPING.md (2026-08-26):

# UI Unit Pin Mapping — STM32G431KB (NUCLEO-G431KB)

> Target MCU: STM32G431KB (LQFP32, 32 pins)
> Display: EA DOGXL240W-7 (240×128 COG LCD, SPI, UC1611S controller)
> EEPROM: 24L256 (I²C)
> CAN transceiver: MCP2562 (CAN 2.0)
> Temperature sensor: LM35 (analog)
> Debug: USART1 (synchronous)

---

## 0. Package Constraint — LQFP32 Available Pins

Only **24 GPIOs** are bonded out on the 32-pin package:

| Port | Available Pins | NOT Available |
|---|---|---|
| PA | PA0–PA15 (16) | — |
| PB | PB0, PB3–PB8 (7) | **PB1, PB2, PB9–PB15 do not exist** |
| PF | PF0, PF1 (oscillator only) | — |
| PG | — | PG10 = NRST (not GPIO) |

**PA13/PA14** are permanently reserved for SWD debug.

---

## 1. Complete Pin Mapping

| Pin | Function | Peripheral / Mode | AF | Dir | Notes |
|-----|---|---|-----|-----|---|
| PA0 | LM35 temperature sensor | ADC1_IN1 | Analog | In | 10 mV/°C, single conversion |
| PA1 | *(free)* | — | — | — | Not assigned |
| PA2 | VCP TX (ST-LINK) | USART2_TX | AF7 | Out | SB1 ON (default) |
| PA3 | VCP RX (ST-LINK) | USART2_RX | AF7 | In | SB12 ON (default) |
| PA4 | Button S1 | GPIO_EXTI4 | — | In | Pull-up, both edges. Trip 1 reset |
| PA5 | Button S2 | GPIO_EXTI5 | — | In | Pull-up, both edges. Trip 2 reset |
| PA6 | Button S3 | GPIO_EXTI6 | — | In | Pull-up, both edges. Display mode / backlight |
| PA7 | LCD Backlight | GPIO_Output | — | Out | Active HIGH (on/off) |
| PA8 | USART1 Clock | USART1_CK | AF7 | Out | Synchronous mode clock output |
| PA9 | Debug USART TX | USART1_TX | AF7 | Out | CN3 pin 2 (labeled RX on board) |
| PA10 | Debug USART RX | USART1_RX | AF7 | In | CN3 pin 1 (labeled TX on board) |
| PA11 | CAN RX | FDCAN1_RX | AF9 | In | From MCP2562 RXD |
| PA12 | CAN TX | FDCAN1_TX | AF9 | Out | To MCP2562 TXD |
| PA13 | SWD debug data | SWDIO | AF0 | I/O | **Never reconfigure** |
| PA14 | SWD debug clock | SWCLK | AF0 | In | **Never reconfigure** |
| PA15 | EEPROM SCL | I2C1_SCL | AF4 | Out | SB3 ON (default) — Arduino A5 |
| PB0 | *(free)* | — | — | — | Not assigned |
| PB3 | SPI1 Clock | SPI1_SCK | AF5 | Out | **Cut SB4** to free from SWO trace |
| PB4 | LCD Chip Select | GPIO_Output | — | Out | Active LOW |
| PB5 | SPI1 MOSI | SPI1_MOSI | AF5 | Out | User LED LD2 on this pin |
| PB6 | LCD Command/Data | GPIO_Output | — | Out | HIGH = data, LOW = command |
| PB7 | EEPROM SDA | I2C1_SDA | AF4 | I/O | SB2 ON (default) — Arduino A4 |
| PB8 | *(not configured)* | — | — | — | BOOT0 pin, locked in .ioc |

**Total pins used:** 18 (of 24 available GPIOs + 2 SWD)
**Free GPIOs:** PA1, PB0, PB8-BOOT0 (3 free pins available)

---

## 2. Peripheral Pin Assignments

### 2.1 SPI1 — EA DOGXL240W-7 Display

| SPI Signal | MCU Pin | AF | Display Pin | Notes |
|---|---|-----|---|---|
| SCK | PB3 | AF5 | 38 (SCK) | Cut SB4 to free from SWO trace |
| MOSI | PB5 | AF5 | 39 (SDA) | User LED LD2 on same pin — acceptable |
| CS (GPIO) | PB4 | — | 36 (CS1) | Direct GPIO, active LOW |
| CD (GPIO) | PB6 | — | 34 (CD) | HIGH = data, LOW = command |
| Backlight | PA7 | — | — | GPIO toggle (on/off) |

**SPI config:** Mode 0 (CPOL=0, CPHA=0), 8-bit, MSB first. 5.3125 Mbit/s (prescaler /32 from 170 MHz APB2).

### 2.2 FDCAN1 — CAN Bus

| Signal | MCU Pin | AF | Transceiver Pin | Notes |
|---|---|-----|---|---|
| TX | PA12 | AF9 | MCP2562 TXD | |
| RX | PA11 | AF9 | MCP2562 RXD | |

**FDCAN config:** CAN 2.0B compatible, ~447 kbit/s.
Clock source: PLL (170 MHz), FDCAN prescaler /76, TimeSeg1=2, TimeSeg2=2.

### 2.3 I2C1 — 24L256 EEPROM

| Signal | MCU Pin | AF | EEPROM Pin | Notes |
|---|---|-----|---|---|
| SCL | PA15 | AF4 | 6 (SCL) | SB3 ON (default) — Arduino A5 |
| SDA | PB7 | AF4 | 5 (SDA) | SB2 ON (default) — Arduino A4 |

**I2C config:** Standard mode (100 kHz), 7-bit addressing.

### 2.4 USART1 — Debug / Logging (Synchronous)

| Signal | MCU Pin | AF | Notes |
|---|---|-----|---|
| TX | PA9 | AF7 | CN3 pin 2 (labeled RX — known board quirk) |
| RX | PA10 | AF7 | CN3 pin 1 (labeled TX — known board quirk) |
| CK | PA8 | AF7 | Synchronous clock output |

**USART1 config:** Synchronous mode, 170 MHz bus clock.

### 2.5 USART2 — VCP (ST-LINK)

| Signal | MCU Pin | AF | Notes |
|---|---|-----|---|
| TX | PA2 | AF7 | Connected to ST-LINK VCP via SB1 |
| RX | PA3 | AF7 | Connected to ST-LINK VCP via SB12 |

**USART2 config:** VCP link to ST-LINK. SB1 and SB12 remain ON (default).

### 2.6 ADC1 — LM35 Temperature Sensor

| Signal | MCU Pin | ADC Channel | Notes |
|---|---|---|---|
| VOUT | PA0 | ADC1_IN1 | 10 mV/°C, 3.3V reference |

**ADC config:** 12-bit, single conversion, software trigger.

### 2.7 GPIO — Buttons

| Button | MCU Pin | EXTI Line | IRQ | Purpose |
|---|---|---|-----|---|
| S1 | PA4 | EXTI4 | EXTI4_IRQn | Long press: reset trip 1 |
| S2 | PA5 | EXTI5 | EXTI9_5_IRQn | Long press: reset trip 2 |
| S3 | PA6 | EXTI6 | EXTI9_5_IRQn | Short: cycle display mode. Long: toggle backlight |

**Config:** Internal pull-up, rising + falling edge interrupt.

### 2.8 GPIO — Outputs

| Function | MCU Pin | Notes |
|---|---|---|
| LCD Backlight | PA7 | Active HIGH, on/off toggle |
| LCD CS | PB4 | Active LOW |
| LCD CD | PB6 | HIGH = data, LOW = command |

---

## 3. Conflict Analysis

### 3.1 Pin-Level AF Conflicts — None

Every pin serves exactly one function. All alternate function selections are mutually exclusive:

| Pin | Assigned Function | Other AFs on Pin | Conflict? |
|-----|---|---|---|
| PA0 | ADC1_IN1 | TIM2_CH1 (AF1), LPUART1_CTS (AF8), OPAMP1_OUT (AF12) | **No** — only ADC used |
| PA1 | *(free)* | TIM2_CH2 (AF1), TIM15_CH1 (AF2), USART2_RTS (AF7), LPUART1_RTS (AF8) | **No** — pin free |
| PA2 | USART2_TX (AF7) | TIM2_CH3 (AF1), LPUART1_TX (AF8), COMP2_OUT (AF10) | **No** — only USART2 used |
| PA3 | USART2_RX (AF7) | TIM2_CH4 (AF1), LPUART1_RX (AF8), COMP2_OUT (AF10) | **No** — only USART2 used |
| PA4 | GPIO EXTI (BTN1) | SPI1_NSS (AF5), SPI3_NSS (AF6), USART2_CK (AF7), ADC1_IN5, DAC1_OUT1 | **No** — only GPIO used |
| PA5 | GPIO EXTI (BTN2) | ADC1_IN5 (AF5), TIM2_ETR (AF1) | **No** — only GPIO used |
| PA6 | GPIO EXTI (BTN3) | ADC1_IN6 (AF5), TIM3_CH1 (AF1) | **No** — only GPIO used |
| PA7 | GPIO (LIGHT) | ADC1_IN8, SPI1_MOSI (AF5), TIM3_CH2 (AF2), TIM17_CH1 (AF2), SAI1_FS_B (AF13) | **No** — only GPIO used |
| PA8 | USART1_CK (AF7) | MCO (AF0), TIM1_CH1 (AF1), SPI1_MOSI (AF6), FDCAN1_TX (AF10) | **No** — only USART1 used |
| PA9 | USART1_TX (AF7) | TIM1_CH2 (AF1), SPI1_SCK (AF6), I2C3_SCL (AF8), FDCAN1_RX (AF10), LPUART1_TX (AF11) | **No** — only USART1 used |
| PA10 | USART1_RX (AF7) | TIM1_CH3 (AF1), SPI1_MISO (AF6), I2C3_SDA (AF8), LPUART1_RX (AF11) | **No** — only USART1 used |
| PA11 | FDCAN1_RX (AF9) | TIM1_CH4 (AF1), COMP1_OUT (AF3), I2C1_SDA (AF4), USART1_CTS (AF7), USB_DM (AF10) | **No** — only FDCAN used |
| PA12 | FDCAN1_TX (AF9) | COMP1_OUT (AF3), I2C1_SCL (AF4), USART1_RTS_DE (AF7), TIM1_ETR (AF9), USB_DP (AF10) | **No** — only FDCAN used |
| PA15 | I2C1_SCL (AF4) | JTDI (AF0), TIM2_CH1 (AF1), TIM8_CH1 (AF2), SPI1_NSS (AF5), USART2_RX (AF7), TIM1_BKIN (AF9) | **No** — only I2C1 used |
| PB3 | SPI1_SCK (AF5) | JTDO (AF0), SPI3_SCK (AF6) | **No** — only SPI1 used |
| PB4 | GPIO (LCD_CS) | NJTRST (AF0), TIM3_CH1 (AF2), SPI1_MISO (AF5), SPI3_MISO (AF6) | **No** — only GPIO used |
| PB5 | SPI1_MOSI (AF5) | LPTIM1_IN1 (AF1), TIM3_CH2 (AF2), I2C1_SMBA (AF4) | **No** — only SPI1 used |
| PB6 | GPIO (LCD_CD) | LPTIM1_ETR (AF1), TIM4_CH1 (AF2), SAI1_FS_B (AF3), I2C1_SCL (AF4), USART1_TX (AF7) | **No** — only GPIO used |
| PB7 | I2C1_SDA (AF4) | LPTIM1_IN2 (AF1), TIM4_CH2 (AF2), SAI1_FS_B (AF3), USART1_RX (AF7) | **No** — only I2C1 used |

### 3.2 Board-Level Constraints — All Satisfied

| Constraint | Status | Action Required |
|---|---|---|
| PA13 = SWDIO | Reserved | None |
| PA14 = SWCLK | Reserved | None |
| PG10/NRST = Reset | Not used as GPIO | None |
| PB3 = SWO (SB4=ON) | Used for SPI1_SCK | **Cut SB4** |
| PB5 = User LED (LD2) | Used for SPI1_MOSI | LED toggles with MOSI — acceptable |
| PB7 = I2C SDA (SB2=ON) | Used for I2C1_SDA | Keep SB2 ON |
| PA15 = I2C SCL (SB3=ON) | Used for I2C1_SCL | Keep SB3 ON |
| PA2 = VCP TX (SB1=ON) | Used for USART2_TX | Keep SB1 ON |
| PA3 = VCP RX (SB12=ON) | Used for USART2_RX | Keep SB12 ON |

### 3.3 Peripheral Resource Conflicts — None

| Resource | Used By | Conflicts With |
|---|---|---|
| SPI1 | Display | Nothing else |
| I2C1 | EEPROM | Nothing else |
| FDCAN1 | CAN bus | Nothing else |
| USART1 | Debug (synchronous) | Nothing else |
| USART2 | VCP (ST-LINK) | Nothing else |
| ADC1 | LM35 | Nothing else |
| EXTI4 | Button S1 | Nothing else |
| EXTI5 | Button S2 | Nothing else |
| EXTI6 | Button S3 | Nothing else |

---

## 4. NUCLEO Board Modifications Required

| Solder Bridge | Default | Required State | Reason |
|---|---|---|---|
| SB1 (VCP TX) | ON | **ON** | Keep PA2 as USART2_TX for VCP |
| SB12 (VCP RX) | ON | **ON** | Keep PA3 as USART2_RX for VCP |
| SB2 (I2C SDA) | ON | **ON** | Keep PB7 as I2C1_SDA on A4 |
| SB3 (I2C SCL) | ON | **ON** | Keep PA15 as I2C1_SCL on A5 |
| SB4 (SWO) | ON | **CUT** | Free PB3 for SPI1_SCK |
| SB8 (PF0→D7) | OFF | OFF | Not needed |
| SB11 (PF1→D8) | OFF | OFF | Not needed |
| SB13 (MCO→HSE) | OFF | OFF | Not used — FDCAN uses PLL clock |
| SB9+SB10 (HSE XTAL) | OFF | OFF | Not needed |

---

## 5. Old vs New Pin Comparison

| Function | Old MCU (STM32F103C8) | New MCU (STM32G431KB) | Change |
|---|---|---|---|
| LCD RS | PA0 | *(removed — SPI display)* | Replaced by CD (PB6) |
| LCD RW | PA1 | *(removed — SPI display)* | Not needed in SPI mode |
| LCD E | PA2 | *(removed — SPI display)* | Not needed in SPI mode |
| LCD D4–D7 | PA3–PA6 | *(removed — SPI display)* | Replaced by SPI |
| LCD SPI SCK | — | PB3 | **New** |
| LCD SPI MOSI | — | PB5 | **New** |
| LCD CS | — | PB4 | **New** |
| LCD CD | — | PB6 | **New** |
| LCD Backlight | PB10 | PA7 | Moved |
| CAN TX | PA12 | PA12 | Same pin! |
| CAN RX | PA11 | PA11 | Same pin! |
| I2C1 SCL | PB6 | PA15 | Moved |
| I2C1 SDA | PB7 | PB7 | Same |
| USART1 TX | PA9 | PA9 | Same |
| USART1 RX | PA10 | PA10 | Same |
| ADC (temp) | PB1 (ADC1_IN9) | PA0 (ADC1_IN1) | Moved |
| Button S1 | PB5 | PA4 | Moved |
| Button S2 | PB4 | PA5 | Moved |
| Button S3 | PB3 | PA6 | Moved |
| Buzzer | PB12 | — | Not assigned in current firmware |
| VCP TX | — | PA2 (USART2) | Uses SB1 (default) |
| VCP RX | — | PA3 (USART2) | Uses SB12 (default) |

---

## 6. Free Pins for Future Expansion

**3 free pins:** PA1, PB0, PB8-BOOT0.

Additional expansion options:
- **Final PCB with STM32G431CB (LQFP48):** adds PB1, PB2, PB9–PB15, PC13–PC15 for 15+ extra GPIOs

---

## 7. Clock Configuration Notes

- **System clock:** 170 MHz (PLL from HSI16, PLLM=/4, PLLN=85)
- **APB1/APB2:** 170 MHz (no prescaler)
- **FDCAN clock:** 170 MHz from PLL; prescaler /76, TimeSeg1=2, TimeSeg2=2 → ~447 kbit/s
- **SPI1 clock:** 170 MHz APB2 / prescaler 32 = 5.3125 Mbit/s
- **I2C1 clock:** 170 MHz (timing register 0x40B285C2 for 100 kHz standard mode)
- **USART1/USART2:** 170 MHz bus clock

---

## 8. Summary

**Key design decisions:**
1. **FDCAN1 on PA11/PA12** — confirmed as CubeMX default for G431; same pins as old bxCAN design
2. **SPI1 on PB3/PB5** — only SPI1 option that doesn't conflict with I2C1 or FDCAN1; MOSI-only (no MISO)
3. **I2C1 on PA15/PB7** — uses default NUCLEO I2C solder bridges (SB2/SB3 ON)
4. **USART1 on PA8/PA9/PA10** — synchronous mode for debug
5. **USART2 on PA2/PA3** — VCP link to ST-LINK (SB1/SB12 ON)
6. **Buttons on PA4/PA5/PA6** — GPIO EXTI with internal pull-up
7. **LCD control signals on PB4 (CS), PB6 (CD), PA7 (backlight)** — GPIO outputs
8. **3 free pins remain** — PA1, PB0, PB8-BOOT0 available for expansion

**Hardware modifications:** Cut SB4 (free PB3 for SPI1_SCK). Keep all other solder bridges at default.

**Errata in MCU_PINS.md:** The AF table lists FDCAN1_TX on PA8 (AF10) and FDCAN1_RX on PA9 (AF10), but CubeMX does not offer FDCAN on these pins for the G431KB. FDCAN1 is confirmed on PA11/PA12 (AF9) per CubeMX and ST Community reports. The MCU_PINS.md FDCAN1 section (listing PA8/PB9/PB10 for TX and PA9/PB11/PB12 for RX) also contradicts the AF table and should be corrected.

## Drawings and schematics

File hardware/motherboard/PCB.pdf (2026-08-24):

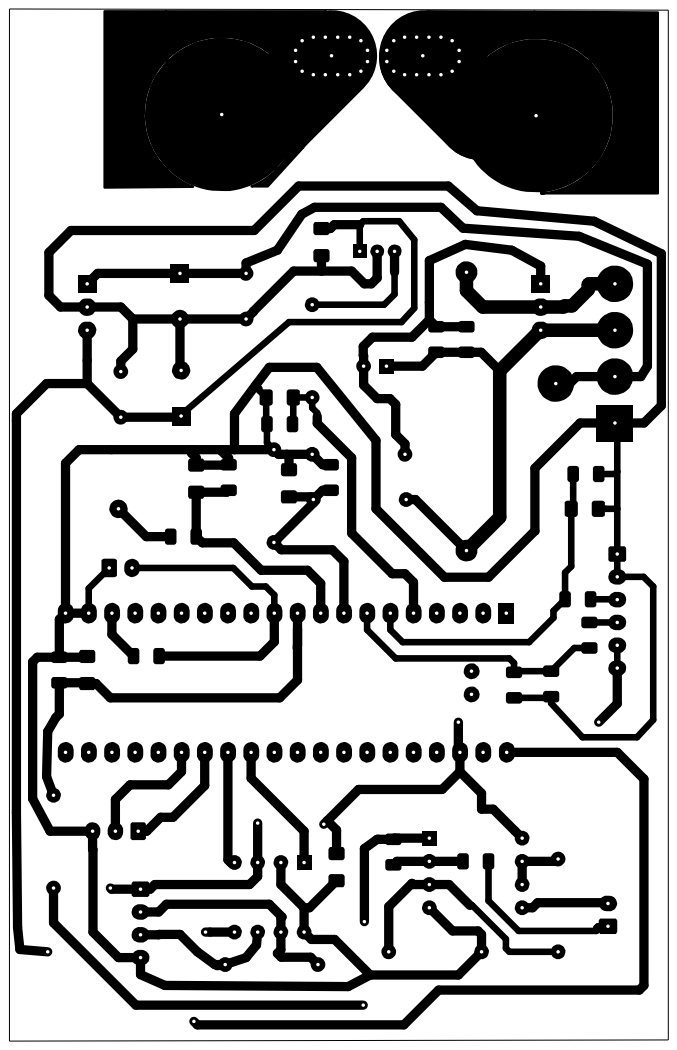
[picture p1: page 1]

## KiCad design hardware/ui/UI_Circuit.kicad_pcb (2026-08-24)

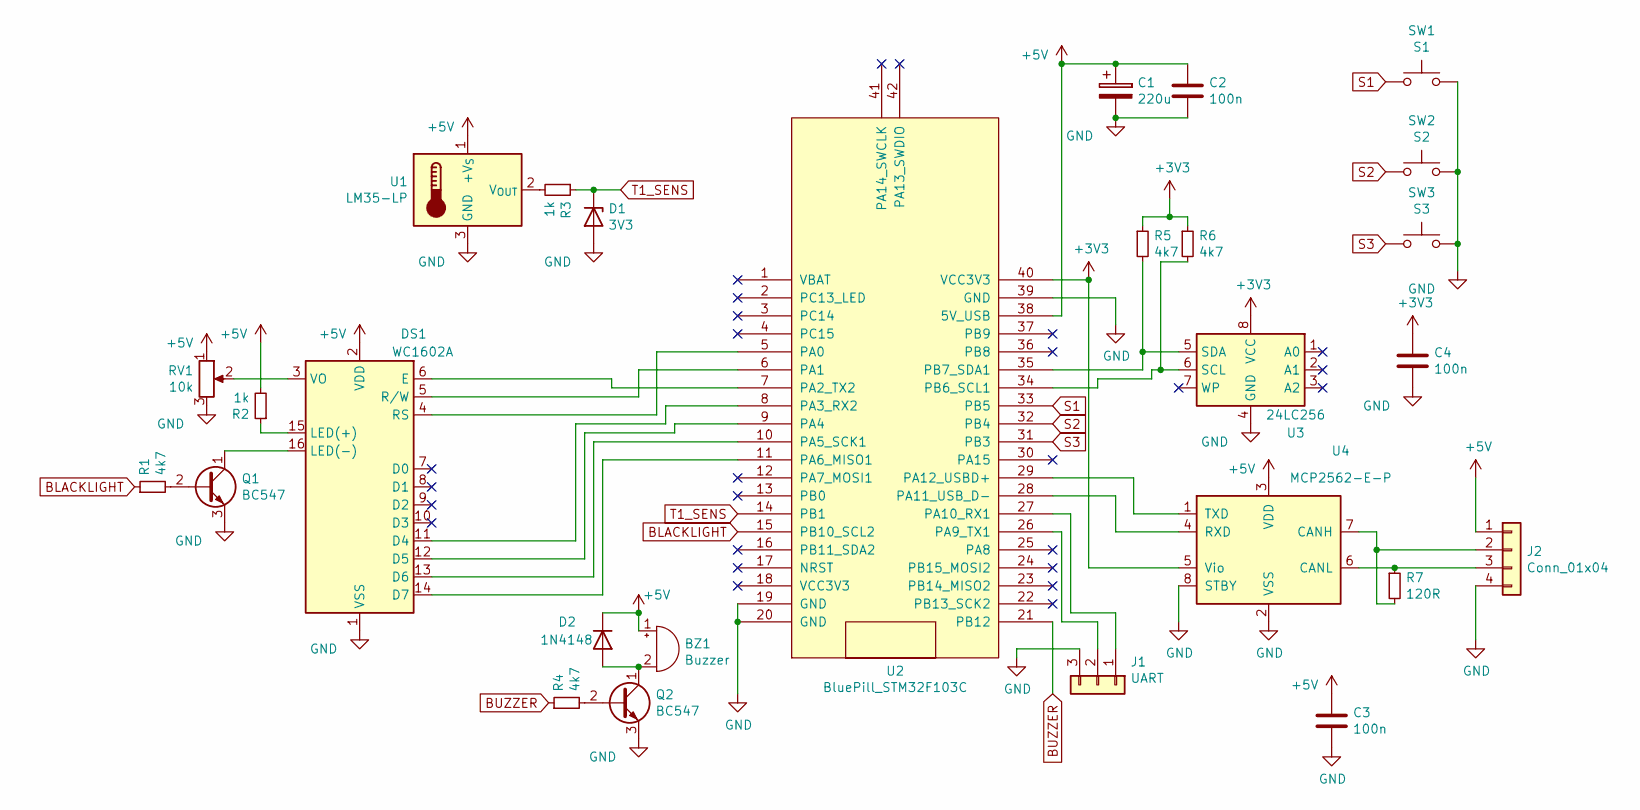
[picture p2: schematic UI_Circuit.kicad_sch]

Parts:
BZ1: Buzzer; Buzzer_15x7.5RM7.6
C1: 220u; CP_Radial_D10.0mm_P5.00mm
C2, C3, C4: 100n; C_1206_3216Metric
D1: 3V3; D_1206_3216Metric
D2: 1N4148; D_DO-35_SOD27_P7.62mm_Horizontal
DS1: WC1602A
J1: UART; PinHeader_1x03_P2.54mm_Vertical
J2: Conn_01x04; JST_EH_B4B-EH-A_1x04_P2.50mm_Vertical
Q1, Q2: BC547; TO-92_HandSolder
R1, R4, R5, R6: 4k7; R_1206_3216Metric
R2, R3: 1k; R_1206_3216Metric
R7: 120R; R_Axial_DIN0207_L6.3mm_D2.5mm_P10.16mm_Horizontal
RV1: 10k; Potentiometer_Piher_PT-6-V_Vertical
SW1: S1; SW_PUSH_6mm_H8mm
SW2: S2; SW_PUSH_6mm_H8mm
SW3: S3; SW_PUSH_6mm_H8mm
U1: LM35-LP; TO-92L_HandSolder
U2: BluePill_STM32F103C
U3: 24LC256; DIP-8_W7.62mm
U4: MCP2562-E-P; DIP-8_W7.62mm

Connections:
+3V3: C4.1, R5.1, R6.1, U2.40 (VCC3V3), U3.8 (VCC), U4.5 (Vio)
+5V: BZ1.1 (+), C1.1, C2.1, C3.1, D2.1 (K), DS1.2 (VDD), J2.1, R2.2, RV1.1, U1.1 (+V_{S}), U2.38 (5V_USB), U4.3 (VDD)
BLACKLIGHT: R1.1, U2.15 (PB10_SCL2)
BUZZER: R4.1, U2.21 (PB12)
GND: C1.2, C2.2, C3.2, C4.2, D1.2 (A), DS1.1 (VSS), J1.3, J2.4, Q1.3 (E), Q2.3 (E), RV1.3, SW1.2, SW2.2, SW3.2, U1.3 (GND), U2.19 (GND), U2.20 (GND), U2.39 (GND), U3.4 (GND), U4.2 (VSS), U4.8 (STBY)
unnamed: BZ1.2 (-), D2.2 (A), Q2.1 (C)
unnamed: DS1.3 (VO), RV1.2
unnamed: DS1.4 (RS), U2.5 (PA0)
unnamed: DS1.5 (R/W), U2.6 (PA1)
unnamed: DS1.6 (E), U2.7 (PA2_TX2)
unnamed: DS1.11 (D4), U2.8 (PA3_RX2)
unnamed: DS1.12 (D5), U2.9 (PA4)
unnamed: DS1.13 (D6), U2.10 (PA5_SCK1)
unnamed: DS1.14 (D7), U2.11 (PA6_MISO1)
unnamed: DS1.15 (LED(+)), R2.1
unnamed: DS1.16 (LED(-)), Q1.1 (C)
unnamed: J1.1, U2.27 (PA10_RX1)
unnamed: J1.2, U2.26 (PA9_TX1)
unnamed: J2.2, R7.2, U4.7 (CANH)
unnamed: J2.3, R7.1, U4.6 (CANL)
unnamed: Q1.2 (B), R1.2
unnamed: Q2.2 (B), R4.2
unnamed: R3.2, U1.2 (V_{OUT})
unnamed: R5.2, U2.35 (PB7_SDA1), U3.5 (SDA)
unnamed: R6.2, U2.34 (PB6_SCL1), U3.6 (SCL)
unnamed: U2.28 (PA11_USB_D-), U4.4 (RXD)
unnamed: U2.29 (PA12_USBD+), U4.1 (TXD)
S1: SW1.1, U2.33 (PB5)
S2: SW2.1, U2.32 (PB4)
S3: SW3.1, U2.31 (PB3)
T1_SENS: D1.1 (K), R3.1, U2.14 (PB1)

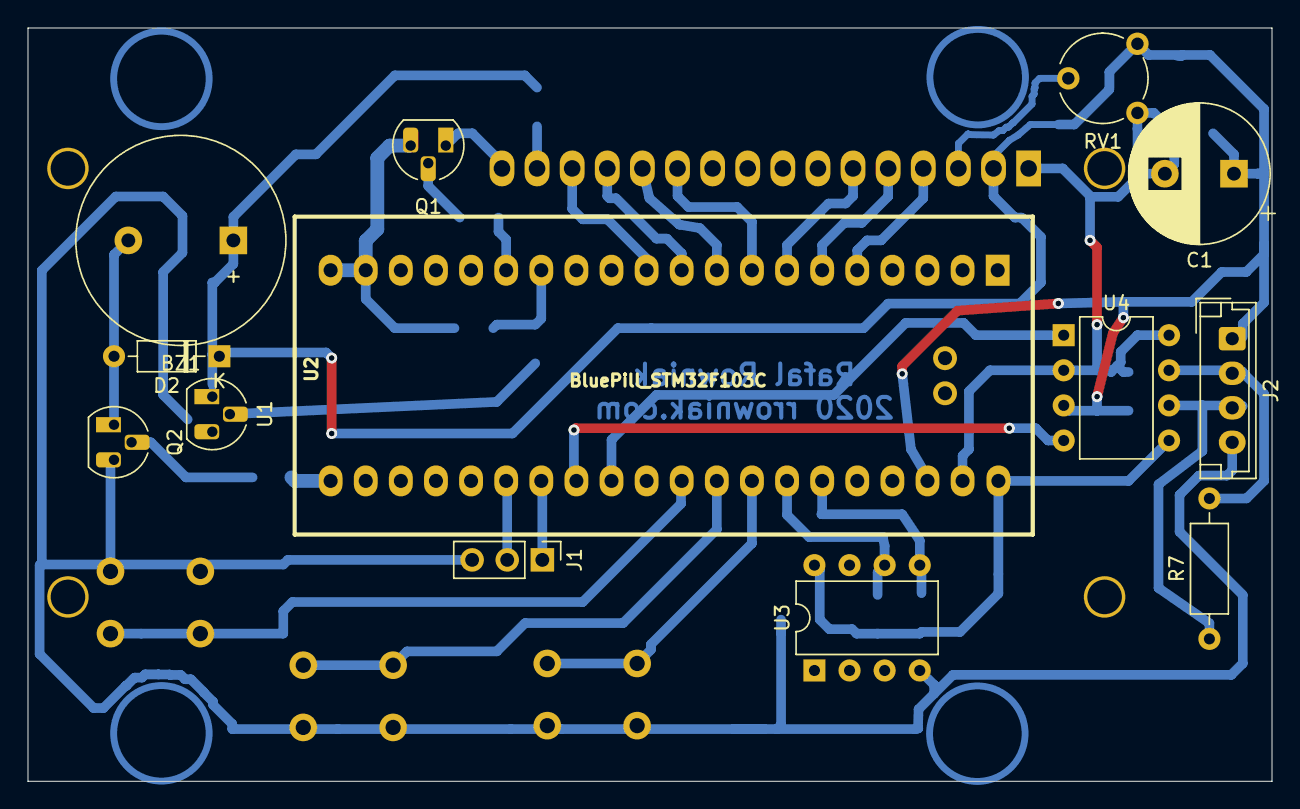
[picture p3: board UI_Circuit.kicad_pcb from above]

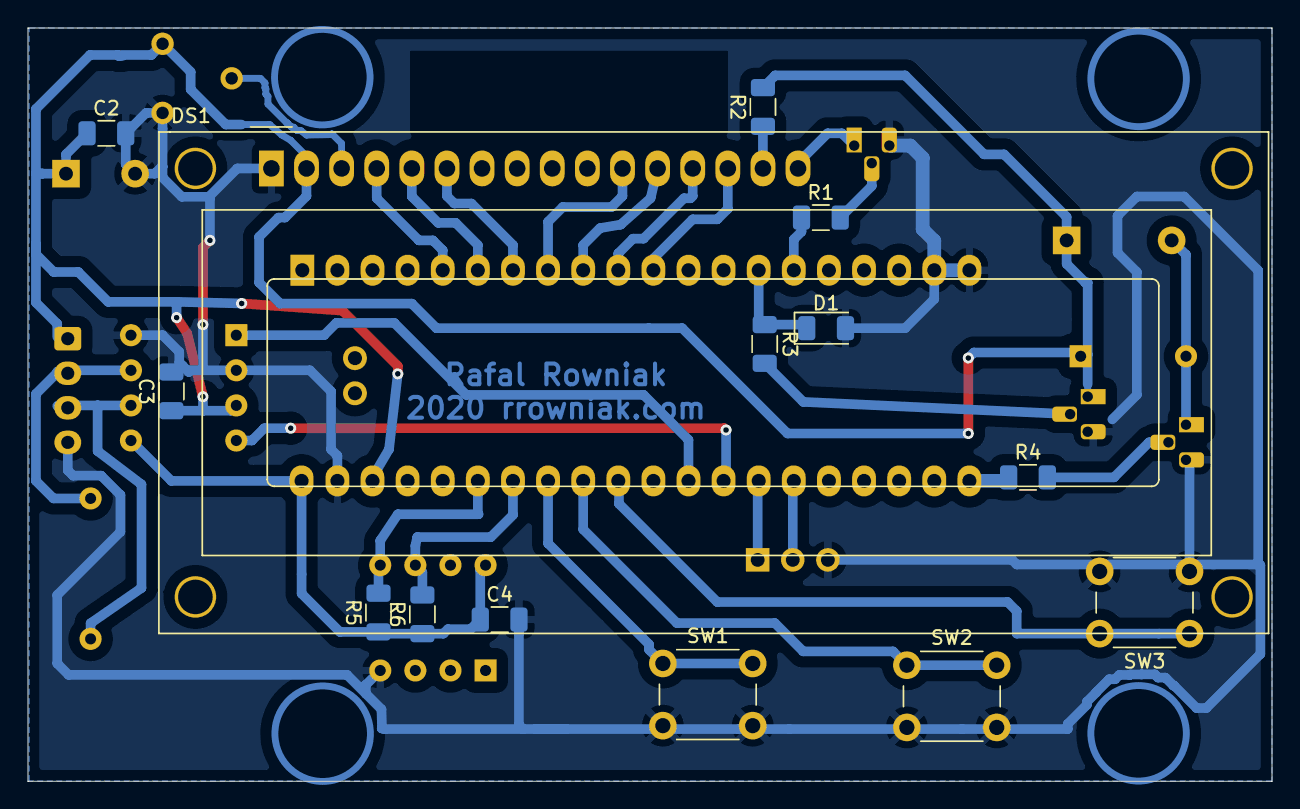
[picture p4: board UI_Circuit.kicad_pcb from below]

Board: 2 copper layers, 90.0 x 54.5 mm, 27 parts (14 on the bottom side), 31 nets.

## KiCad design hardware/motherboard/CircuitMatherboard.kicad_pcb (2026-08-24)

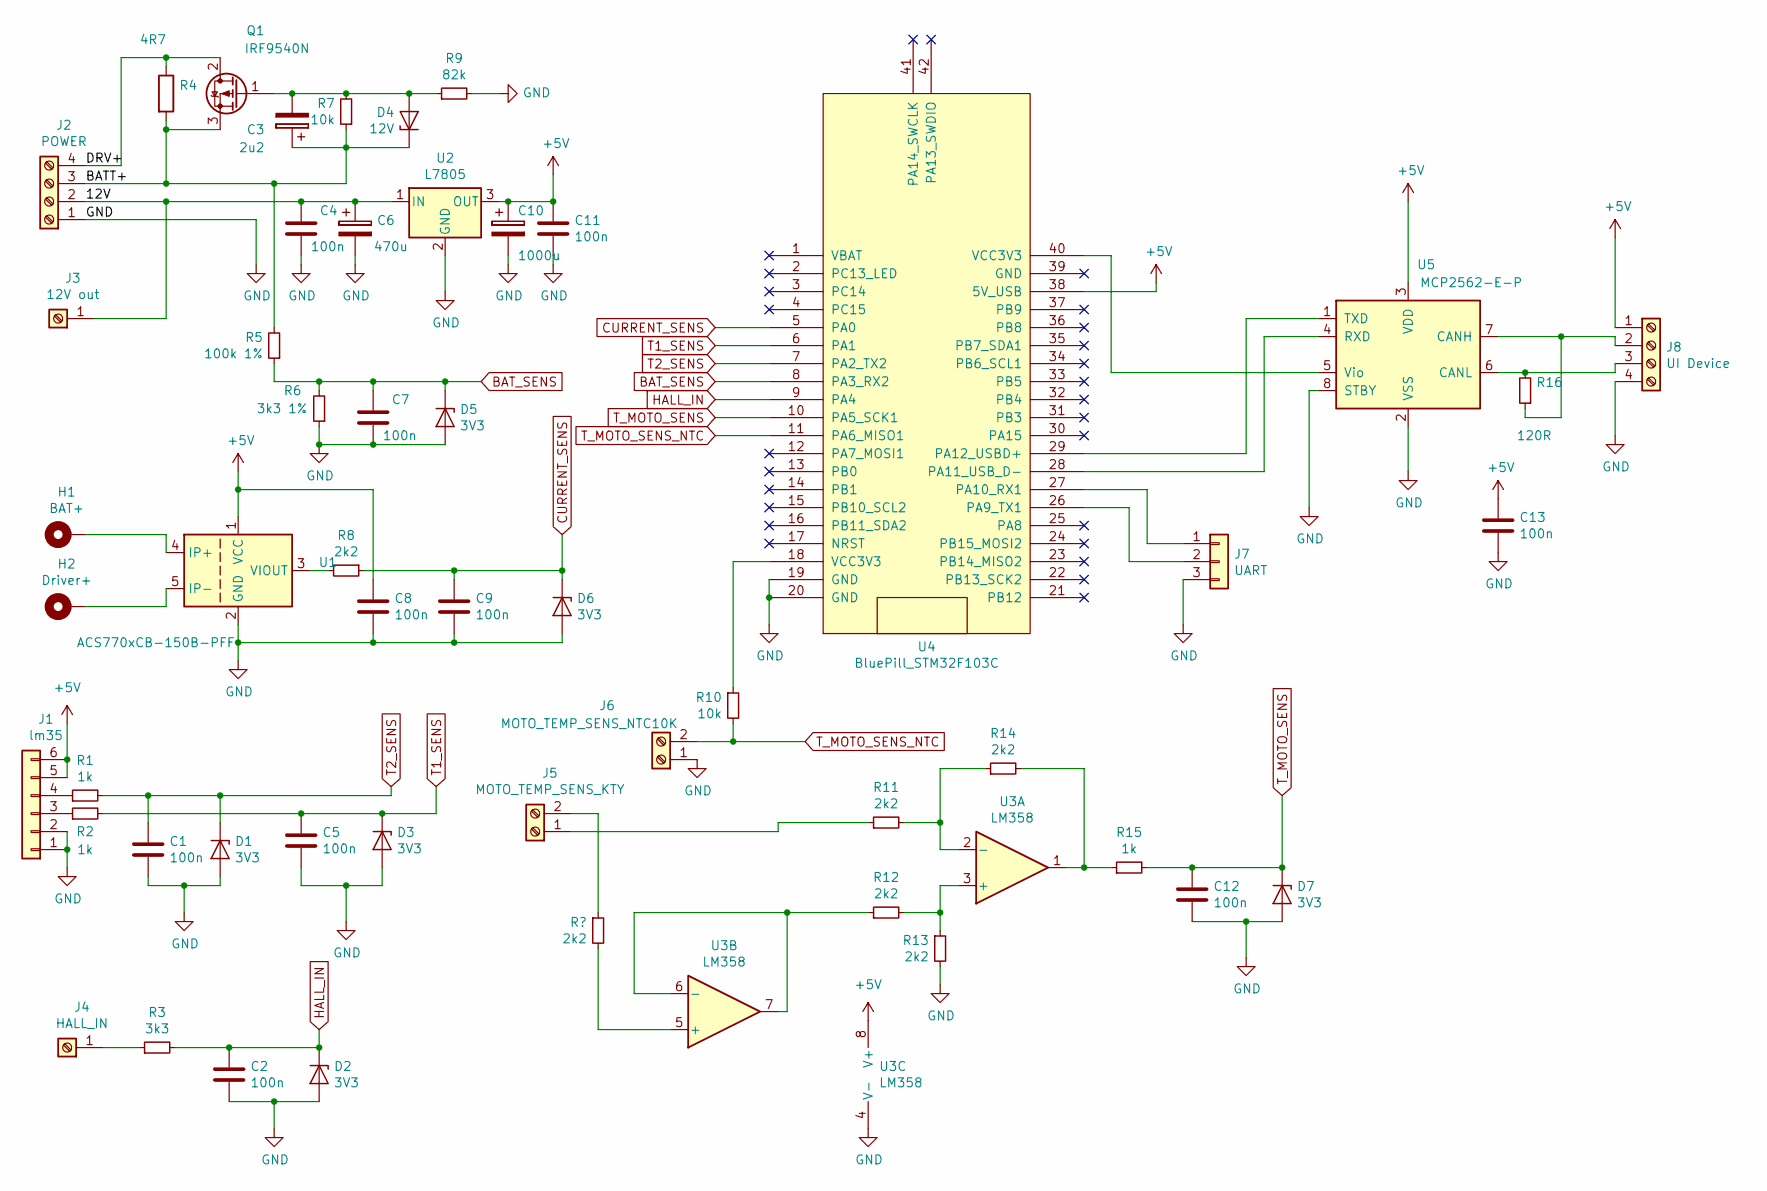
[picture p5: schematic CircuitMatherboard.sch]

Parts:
C1: 100n; C_1206_3216Metric
C2, C5, C7, C8, C9, C12, C13: 100n; C_1206_3216Metric_Pad1.42x1.75mm_HandSolder
C3: 2u2; CP_Radial_D5.0mm_P2.50mm
C4, C11: 100n; C_Disc_D4.3mm_W1.9mm_P5.00mm
C6: 470u; CP_Radial_D10.0mm_P5.00mm
C10: 1000u; CP_Radial_D10.0mm_P5.00mm
D1, D2, D3, D5, D6, D7: 3V3; D_1206_3216Metric
D4: 12V; D_1206_3216Metric
H1: BAT+; MountingHole_8.4mm_M8_Pad
H2: Driver+; MountingHole_8.4mm_M8_Pad
J1: lm35; JST_EH_B6B-EH-A_1x06_P2.50mm_Vertical
J2: POWER; SolderWirePad_1x04_P5.08mm_Drill1.5mm
J3: 12V out; SolderWirePad_1x01_Drill1.5mm
J4: HALL_IN; SolderWirePad_1x01_Drill0.8mm
J5: MOTO_TEMP_SENS_KTY; JST_EH_B2B-EH-A_1x02_P2.50mm_Vertical
J6: MOTO_TEMP_SENS_NTC10K; JST_EH_B2B-EH-A_1x02_P2.50mm_Vertical
J7: UART; JST_EH_B3B-EH-A_1x03_P2.50mm_Vertical
J8: UI Device; JST_EH_B4B-EH-A_1x04_P2.50mm_Vertical
Q1: IRF9540N; TO-220-3_Vertical
R1, R2: 1k; R_1206_3216Metric
R3: 3k3; R_1206_3216Metric
R4: 4R7; R_Axial_Power_L25.0mm_W9.0mm_P30.48mm
R5: 100k 1%; R_Axial_DIN0207_L6.3mm_D2.5mm_P10.16mm_Horizontal
R6: 3k3 1%; R_Axial_DIN0207_L6.3mm_D2.5mm_P10.16mm_Horizontal
R7, R10: 10k; R_1206_3216Metric
R8, R12, R13: 2k2; R_Axial_DIN0207_L6.3mm_D2.5mm_P10.16mm_Horizontal
R9: 82k; R_Axial_DIN0207_L6.3mm_D2.5mm_P10.16mm_Horizontal
R11, R14: 2k2; R_1206_3216Metric
R15: 1k; R_Axial_DIN0207_L6.3mm_D2.5mm_P10.16mm_Horizontal
R16: 120R; R_Axial_DIN0207_L6.3mm_D2.5mm_P10.16mm_Horizontal
U1: ACS770xCB-150B-PFF; Allegro_CB_PFF
U2: L7805; TO-220-3_Vertical
U3: LM358; DIP-8_W7.62mm
U4: BluePill_STM32F103C
U5: MCP2562-E-P; DIP-8_W7.62mm

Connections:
+5V: C8.1, C10.1, C11.1, C13.1, J1.5, J1.6, J8.1, U1.1 (VCC), U2.3 (OUT), U3.8 (V+), U4.38 (5V_USB), U5.3 (VDD)
/12V: C4.1, C6.1, J2.2, J3.1, U2.1 (IN)
/BATT+: C3.1, D4.1 (K), J2.3, Q1.3 (S), R4.2, R5.2, R7.1
/DRV+: J2.4, Q1.2 (D), R4.1
BAT_SENS: C7.1, D5.1 (K), R5.1, R6.2, U4.8 (PA3_RX2)
CURRENT_SENS: C9.1, D6.1 (K), R8.1, U4.5 (PA0)
GND: C1.2, C2.2, C4.2, C5.2, C6.2, C7.2, C8.2, C9.2, C10.2, C11.2, C12.2, C13.2, D1.2 (A), D2.2 (A), D3.2 (A), D5.2 (A), D6.2 (A), D7.2 (A), J1.1, J1.2, J2.1, J6.1, J7.3, J8.4, R6.1, R9.2, R13.2, U1.2 (GND), U2.2 (GND), U3.4 (V-), U4.19 (GND), U4.20 (GND), U5.2 (VSS), U5.8 (STBY)
HALL_IN: C2.1, D2.1 (K), R3.2, U4.9 (PA4)
unnamed: C3.2, D4.2 (A), Q1.1 (G), R7.2, R9.1
unnamed: H1.1, U1.4 (IP+)
unnamed: H2.1, U1.5 (IP-)
unnamed: J1.3, R2.1
unnamed: J1.4, R1.1
unnamed: J4.1, R3.1
unnamed: J5.1, R11.1
unnamed: J5.2, U3.5 (+)
unnamed: J7.1, U4.27 (PA10_RX1)
unnamed: J7.2, U4.26 (PA9_TX1)
unnamed: J8.2, R16.1, U5.7 (CANH)
unnamed: J8.3, R16.2, U5.6 (CANL)
unnamed: R8.2, U1.3 (VIOUT)
unnamed: R10.1, U4.18 (VCC3V3)
unnamed: R11.2, R14.1, U3.2 (-)
unnamed: R12.1, U3.6 (-), U3.7
unnamed: R12.2, R13.1, U3.3 (+)
unnamed: R14.2, R15.1, U3.1
unnamed: U4.28 (PA11_USB_D-), U5.4 (RXD)
unnamed: U4.29 (PA12_USBD+), U5.1 (TXD)
unnamed: U4.40 (VCC3V3), U5.5 (Vio)
T1_SENS: C5.1, D3.1 (K), R2.2, U4.6 (PA1)
T2_SENS: C1.1, D1.1 (K), R1.2, U4.7 (PA2_TX2)
T_MOTO_SENS: C12.1, D7.1 (K), R15.2, U4.10 (PA5_SCK1)
T_MOTO_SENS_NTC: J6.2, R10.2, U4.11 (PA6_MISO1)

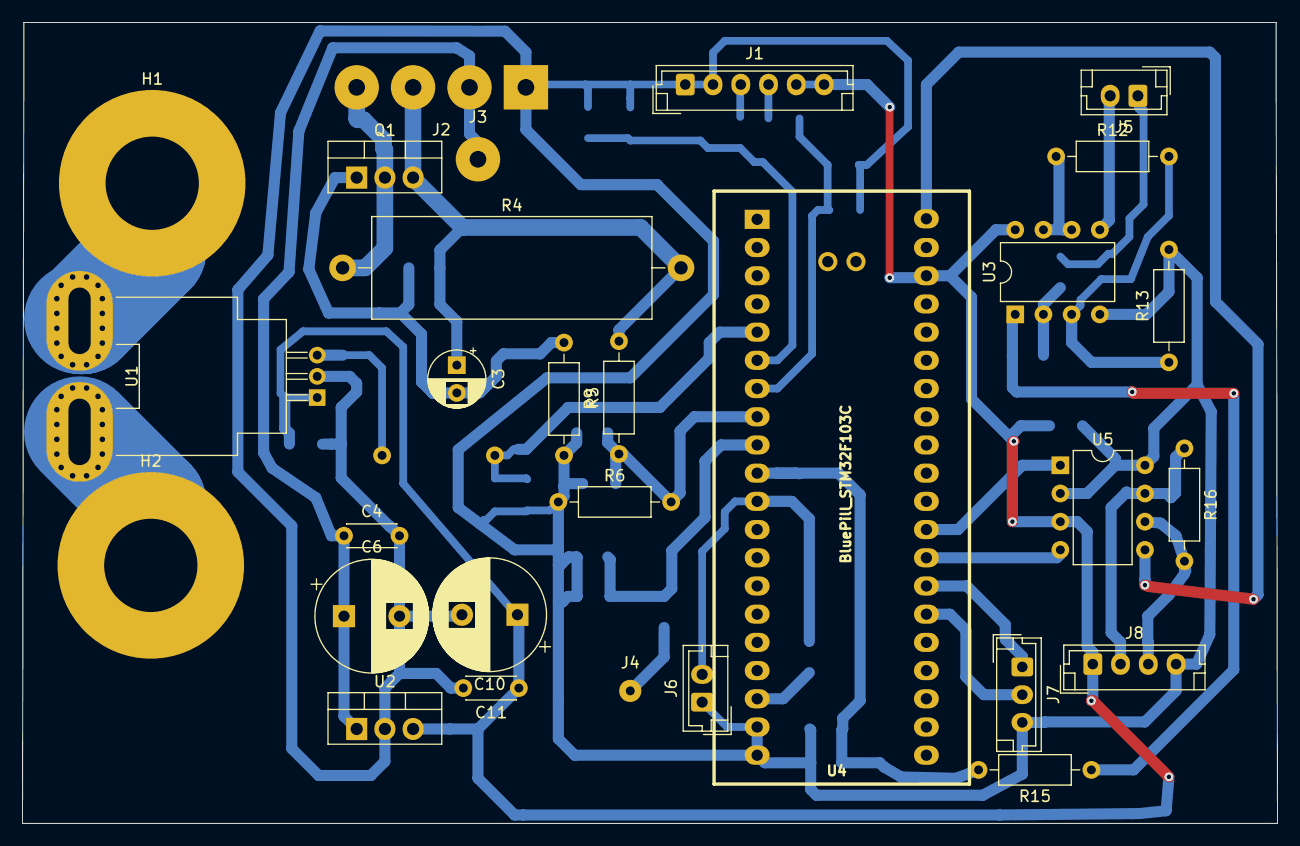
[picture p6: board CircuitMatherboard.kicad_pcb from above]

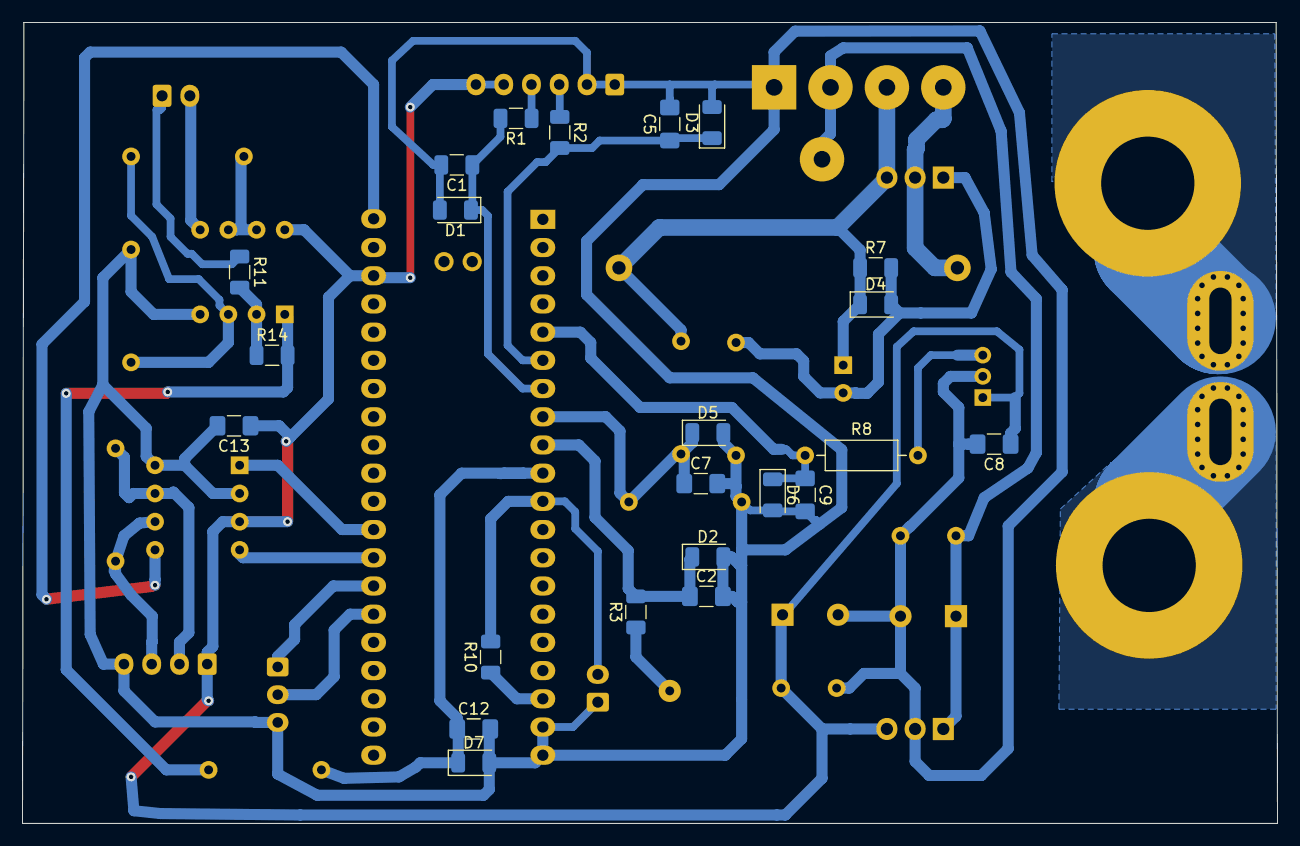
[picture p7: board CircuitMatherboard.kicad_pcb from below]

Board: 2 copper layers, 113.0 x 72.1 mm, 52 parts (23 on the bottom side), 33 nets.

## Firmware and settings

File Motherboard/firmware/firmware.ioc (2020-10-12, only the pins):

Mcu.UserName=STM32F103C8Tx
PA6.GPIO_Label=T4_SENS
PD1-OSC_OUT.Signal=RCC_OSC_OUT
PA12.Signal=CAN_TX
PA6.Signal=ADCx_IN6
PA2.GPIO_Label=T2_SENS
PA10.Signal=USART1_RX
PA4.GPIO_Label=HALL_IN
PA3.Signal=ADCx_IN3
PD0-OSC_IN.Signal=RCC_OSC_IN
PA0-WKUP.GPIO_Label=CURRENT_SENS
PA0-WKUP.Signal=ADCx_IN0
PA9.Signal=USART1_TX
PA1.Signal=ADCx_IN1
PA5.Signal=ADCx_IN5
PA1.GPIO_Label=T1_SENS
PA2.Signal=ADCx_IN2
PA4.Signal=GPXTI4
PA5.GPIO_Label=T3_SENS
PA11.Signal=CAN_RX
PA3.GPIO_Label=BAT_SENS

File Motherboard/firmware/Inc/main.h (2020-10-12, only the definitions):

#define CURRENT_SENS_Pin GPIO_PIN_0
#define CURRENT_SENS_GPIO_Port GPIOA
#define T1_SENS_Pin GPIO_PIN_1
#define T1_SENS_GPIO_Port GPIOA
#define T2_SENS_Pin GPIO_PIN_2
#define T2_SENS_GPIO_Port GPIOA
#define BAT_SENS_Pin GPIO_PIN_3
#define BAT_SENS_GPIO_Port GPIOA
#define HALL_IN_Pin GPIO_PIN_4
#define HALL_IN_GPIO_Port GPIOA
#define HALL_IN_EXTI_IRQn EXTI4_IRQn
#define T3_SENS_Pin GPIO_PIN_5
#define T3_SENS_GPIO_Port GPIOA
#define T4_SENS_Pin GPIO_PIN_6
#define T4_SENS_GPIO_Port GPIOA

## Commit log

2026-08-24 Schematics added
    [CircuitMatherboard.kicad_pcb, CircuitMatherboard.sch, UI_Circuit.kicad_pcb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]
2026-08-26 New UI firmware project - init
    [UI_Circuit.kicad_sch, UI_Circuit_new.kicad_sch]
2026-08-28 Minimal UI firmware which works with Nucleo board + LCD driver implementation
2026-09-02 x-large 24x48 digit font + redesigned main screen
    - New font_xlarge: 24x48 column-major bitmap font for digits, '.', '-'
    - Generated via disk-swept stroke engine (filled circles swept along
    centerline paths) for smooth diagonals and clean curve junctions
    - screens.c: 16x16 status icons, speed in font_xlarge, single battery
    icon + SOC% in font_xlarge, voltage/range in font_medium
    - Firmware: 33564 text, 104 data, 6400 bss

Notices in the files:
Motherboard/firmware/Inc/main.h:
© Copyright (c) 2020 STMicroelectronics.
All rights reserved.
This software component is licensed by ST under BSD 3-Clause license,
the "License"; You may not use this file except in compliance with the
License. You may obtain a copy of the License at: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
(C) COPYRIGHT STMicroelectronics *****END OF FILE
